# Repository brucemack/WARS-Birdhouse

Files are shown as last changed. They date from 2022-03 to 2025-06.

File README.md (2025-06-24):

WARS LoRa Birdhouse Project
===========================

Looking for a different way to tweet?  This project explores the potential of using low-cost/low-bandwidth LoRa radios to build simple mesh networks that can pass text messages around town.  Networks of this type could be useful for emergency communications or 
other applications that can take advantage of the fully-autonomous (carbon-neutral) nature of the birdhouse repeater stations. This 
project is being undertaken by members of the Wellesley Amateur Radio Society, W1TKZ.  The design is 
made available for amateur (non-commercial) purposes in the spirit of experimentation and knowledge sharing
amongst the ham community.  At the very least, we're creating homes for some lucky birds in our area.

Please contact Bruce MacKinnon (KC1FSZ) if you have technical questions.  I am 
interested in home-brew radio projects, many of which can be 
found [on my QRZ page](https://www.qrz.com/db/kc1fsz). 

The [project WIKI is located here](https://github.com/brucemack/WARS-Birdhouse/wiki).

Will this bird fly?  Let's find out!  

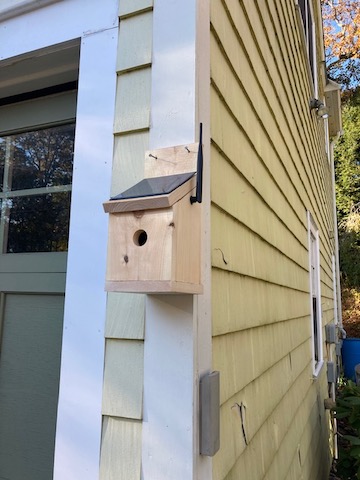
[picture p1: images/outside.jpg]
Birdhouse


Publicity
=========

* This project is mentioned in an excellent new book called [Other Networks: A Radical Technology Sourcebook](https://www.amazon.com/Other-Networks-Radical-Technology-Sourcebook/dp/1944860657) written by Dr. Lori Emerson, Associate Professor of Media Studies, Founding Director of the Media Archaeology Lab, and Director of the Intermedia Art, Writing and Performance Program at the University of Colorado Boulder. I was flattered that Dr. Emerson considered this technology to be "radical" enough to be included in her book, but it's probably not as radical as some of the other technologies she describes including a faster-than-light communications network and a pasilalinic-sympathetic compass.
* An article about this project (co-authored with Dan Brown W1DAN) appears in the Club Station column of the July 2023 issue of [ARRL QST Magazine](https://www.arrl.org/qst). It was nice of the League to publish this.
* A nice Hackaday article [can be found here](https://hackaday.com/2022/04/09/lora-powered-birdhouses-enable-wireless-networking-when-the-internets-down/).  I found this article amusing given its implication that our network could be used as a backup when the Internet was down.  I've not tried streaming Netflix over LoRa, but I'm guessing the video quality won't be great. :-)
* The Zero Retries newsletter covered the project [in June of 2023](https://www.zeroretries.org/i/126932222/thoughts-on-amateur-radio-adjacent-technologies-lora). Steve Stroh N8GNJ does a nice job with this widely-read newsletter and I was honored to be called "woefully misinformed" and "shortsighted" in his article.  As Lindsay Lohan once said, there is no such thing as bad publicity!

Design Overview
================

Nodes on the network are autonomous, solar-powered birdhouses that each contain a +20dBm/100mW radio (Semtech SX1276).  These birdhouses will run 24x7 assuming reasonable weather conditions.  USB-connected desktop nodes are used to access the network from a computer via serial connection.  An internet gateway node is also 
under development. 

LoRa range experiments have been widely documented.  Your milage will vary considerably depending on terrain, 
station hight, etc. Testing shows that 1 km link ranges are reasonable in suburban areas. 

Birdhouse packaging was chosen in order to blend into the surroundings more easily.  We want this project to be environmentally friendly.

Low-power, solar design allows the birdhouses to be 100% autonomous.  This makes it relatively easy to install a repeater station in any location that has good sun exposure and good visibility to other stations. 

The desktop station model is powered by the USB connection, does not have the battery/solar components, but 
is identical to the birdhouse repeaters from an RF/firmware perspective.

The birdhouse is run by an ESP32 microcontroller at the moment, although this decision is under  consideration.  A more power-efficient STM32 prototype is being worked on.

Commodity components are being used to keep birdhouse costs to a minimum.  Our goal is to keep the node cost under $50 USD. 

The software supports a simple message routing protocol that allows packets to "hop" between houses to reach their final destination.  Other control packets are used to extract engineering data and to control 
message routing.

The 33cm ham band (902-928 MHz) is used given that this is an experimental technology and **is not FCC Part 15 certified** at the moment.  All 
nodes must be installed/operated by FCC licensed amateur/ham radio operators under Part 97 rules.

A proof-of-concept network of 5 stations has been constructed in Wellesley, MA.  Messages have been successfully routed back and forth across the entire mesh, including hops between birdhouses that were separated by approximately 1 kilometer.  Antenna height is important, as always.  The houses have been subjected to bad New England weather conditions including snow, ice, extended periods of cloudy weather and sub-zero temperatures.  It is an open question as to how the system will perform when our trees have leaves on them again!

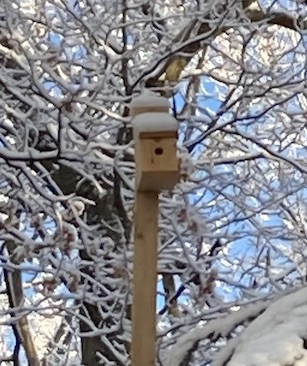
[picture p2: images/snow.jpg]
Snow


A 15 node beta network is currently in the planning stages.  This includes upgrades of the hardware and firmware.

If you are interested in _high-speed_ mesh networks built using commercial hardware this project might not be your thing.  Please take a look at AREDN (https://www.arednmesh.org) instead.  The AREDN team is doing great work.

Architecture Overview
=====================

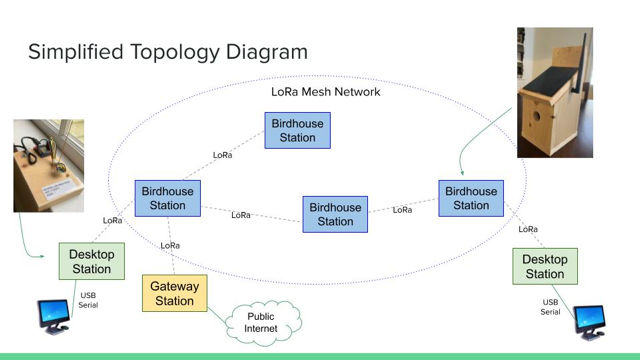
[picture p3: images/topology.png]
Architecture


How Do I Access The Network?
============================

Users access the network using desktop stations that are fitted with a USB serial port.  The desktop station runs exactly the same firmware as the birdhouse repeater.  A serial command protocol is used to send and receive messages on the network.  The desktop stations have all of the required RF components and are full-fledged nodes on the network (with their own addresses).  Desktop nodes don't use the solar/battery installation since they can be powered from the USB port.

Currently users interact with the network using a conventional serial terminal running on a PC (ie. PUTTY or something similar).  No special software is required.  A Python desktop user interface is planned to improve ergonomics.  The serial commands are described in a later section.

The expectation is that users will install a birdhouse station at some 
advantageous location on their property in order to join the network and
increase the network coverage area.  This
means that the required line-of-sight for the desktop station is much less 
important - it's a "short hop" onto  the network.

The other option is to connect the desktop station to a quality antenna 
using a longer feed-line and avoid the need for two stations.  Either configuration 
is fine.

The packaging for the desktop station has not yet been finalized.  At the moment 
the parts are mounted on a block of wood, as pictured below.  A resonant vertical antenna
and USB cable are included with the package.

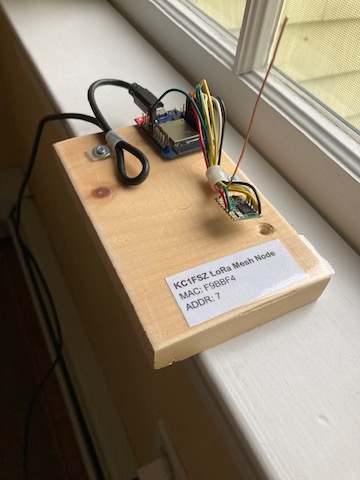
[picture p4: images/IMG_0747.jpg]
Desktop Node


How Can I Get A Birdhouse?
==========================

Hardware/firmware is still being refined as part of a club project.  All firmware, KiCAD files, and woodworking
dimensions are available on this site for anyone who wants to build a birdhouse for themselves.

After our next hardware iteration (V2) is tested we will be making the components available in kit form.

If you live in a strategic location at high elevation and you would like a fully-assembled, tested station we will be happy to provide one free of charge. :-)

Please contact the network administrator to be assigned a node address on the network.

Do I Need To Be A Ham To Use The Network?
=========================================

Yes. The radio module we are using is not Part 15 certified 
so it must be run using Part 97 (amateur) rules.  We are currently doing research on a non-ham ISM Part 15 version of the network 
to make it easy for non-licensed users to join the fun.  If anyone has expertise in this area please add a comment to [the discussion this topic in GitHub](https://github.com/brucemack/WARS-Birdhouse/discussions/2).

Per FCC rules, Part 15 and Part 97 networks will not talk to each other.

Protocol Documentation
======================

The network runs on the 33cm (902-928 MHz) amateur band.  We are running on 906.5 MHz, which lies
in the digital portion of the ARRL band plan for 33cm.  According to the New England Spectrum Management Council (NESMC, https://www.nesmc.org/) 902 MHz band plan, this frequency is in the "mixed use" section of the band.  Our frequency has been registered in the NESMC database to ensure proper coordination with other uses of this band.

The LoRa message payload is documented here in compliance with FCC regulations.  There is no encryption 
used anywhere in the design.  The information contained here is all that a listener would need to interpret the messages.

The standard LoRa physical packet format is used.  Particulars on LoRa parameters:

* 125k bandwidth mode
* CRC enabled, 4/5 coding rate
* Explicit header mode is used
* LoRa spreading factor 9
* 12 symbol preamble

Here is a summary of the physical layer packet format from the Semtech documentation:

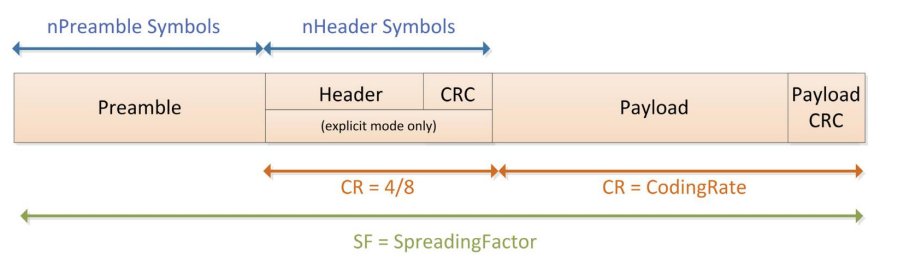
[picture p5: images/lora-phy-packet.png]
packet


A much more detailed explanation of [the LoRa encoding can be found here](https://www.epfl.ch/labs/tcl/wp-content/uploads/2020/02/Reverse_Eng_Report.pdf).

The payload above contains a 36-byte header followed by a variable length packet format.  Particulars:

* 36-byte fixed size. 
* Version (PV) is 2 (at the moment).
* Packet type (PT) describes the nature/handling of the message.  More on types below.
* Packet ID (PID) is used for acknowledgement and duplicate packet elimination.  16-bit integer (little endian).
* Call signs are in ASCII format, padded with spaces as needed.
* Source/destination addresses are 16-bit integer (little endian).  More on addresses below.

packet

### Station Addressing Scheme

Each station is assigned a 16-bit address. Some addresses have special significance:
* 0x0000: Not used
* 0x0001 through 0xffef: Used for normal stations on the network.
* 0xfff0 through 0xfffd: Un-routed stations used for administrative/maintenance purposes.
* 0xfffe: Gateway station to other meshes
* 0xffff: The broadcast address

### Packet Types

Packet types are interpreted as follows:
* 0: Not used
* 1: General acknowledgement packet, used for reliable delivery.
* 2: Station ID/beacon packet.
* 3: Ping request.
* 4: Ping response (pong).
* 5: Station engineering data request.
* 6: Station engineering data response.  
  * See below for details of response.
* 7: Network path test request.  
  * Stations will add their node ID and last-hop RSSI data to this message as it is routed through the network.
* 8: Network path test response.  
  * Stations will add their node ID and last-hop RSSI data to this message as it is routed through the network.
* 9: Set security seed.  Used to establish the seed used to validate privileged requests.
* 10: Set route request.  (A privileged operation)
* 11: Get route data request.
* 12: Get route data response.
* 13: Discover route request (FUTURE USE).
* 14: Discover route response (FUTURE USE).
* 15: Station reset request. (A privileged operation)
* 16: Set station clock request. (A privileged operation)
* 17: Reset engineering counters request.
* 18: Firmware update request (FUTURE USE, privileged)
* 19-31: (RESERVED)
* 32: Routine text traffic.
  * ASCII, free-text payload.  Variable size, max size is 128 bytes.
* 33: Priority/emergency text traffic.
  * ASCII, free-text payload.  Variable size, max size is 128 bytes.
* 34: Routine binary/data traffic.
  * Variable size, max size is 128 bytes.  *NO ENCRYPTION ALLOWED!*
* 35: Priority/emergency binary/data traffic.
  * Variable size, max size is 128 bytes.  *NO ENCRYPTION ALLOWED!*
* 36: Station alert.  Used for sounding audible alarms, etc.

### Acknowledgement/De-Duplication 

Most packet types are acknowledged on each hop.  Packet type 1 is used for this purpose.  Note that this 
doesn't mean that the acknowledgement reaches the original sender, it just means that each 
station will get an ACK to indicate that a packet has been handed off to the next station in 
the route path.

Acknowledgement packets (type 1) and Station ID packets (type 2) are not acknowledged.

Stations will maintain a counter for each node that is receives packet from.  Duplicate packets
will be discarded based on the Packet ID counter.  A window will be used to avoid confusion when 
the counter wraps.

#### Station Engineering Data Packet

This packet returns technical data that is used to monitor the state of 
a station.  Format is a follows:

* 0-1: Firmware version 
* 2-3: Battery voltage in mV
* 4-5: Panel voltage in mV
* 6-9: Uptime in seconds
* 10-13: Time (in seconds since the epoch)
* 14-15: Boot count
* 16-17: Sleep count 
* 18-19: Receive packet count 
* 20-21: Routing error count
* 22-23: Temperature (when option installed)
* 24-25: Humidity (when option installed)
* 26-27: Device class
  * 0: Unspecified
  * 1: WARS Desktop ESP32
  * 2: WARS Birdhouse ESP32
  * 3: WARS Mesh gateway STM32
  * 4: WARS Internet gateway STM32
  * 5: WARS Desktop STM32
  * 6: WARS Birdhouse STM32
* 28-29: Device revision
* 30-31: Wrong-node receive packet count 

2 byte and 4 byte integers are in little-endian format.

Hardware Overview (Electronics)
===============================

The birdhouse repeater prototype (external view):

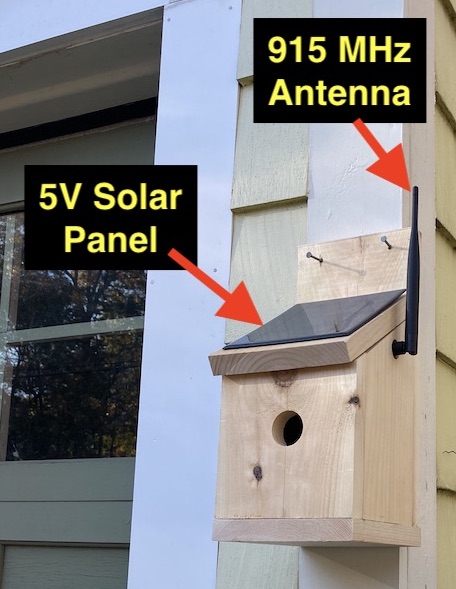
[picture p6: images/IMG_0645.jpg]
house1


The birdhouse repeater prototype (internal electronics view):

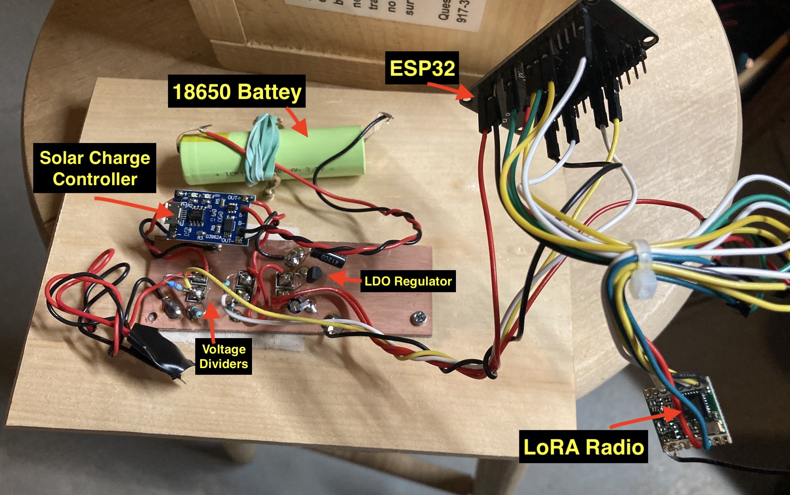
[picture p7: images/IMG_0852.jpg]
house2


A tower-mounted birdhouse repeater prototype at the QTH of KC1FSZ:

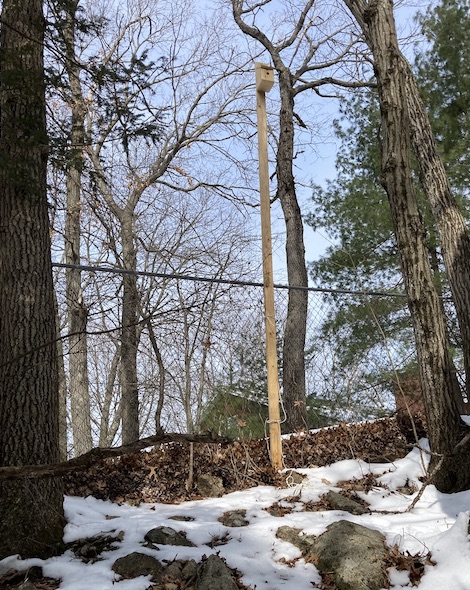
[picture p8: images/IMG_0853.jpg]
house3


A custom PCB (V2) has been developed to improve integration and to make things easier for kit builders without SMD soldering capability.  This board also provides an SMA connector to make antenna experimentation easier.

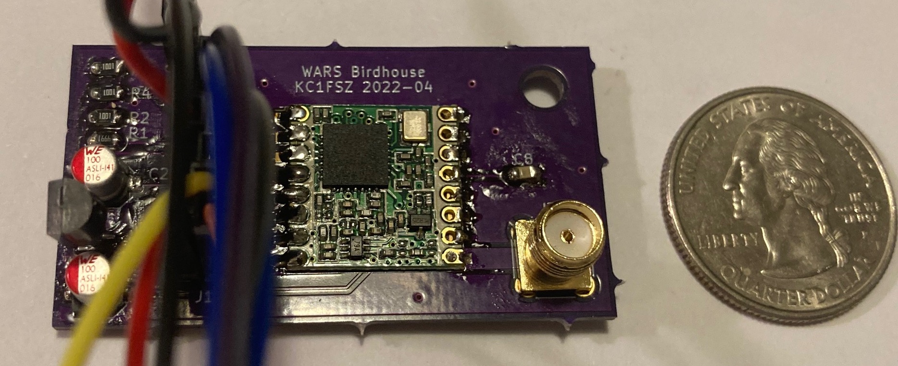
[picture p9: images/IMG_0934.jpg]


Hardware Notes
--------------
* Voltage readings are taken on solar panels and batteries.
* The V2 schematic can be found [here](https://github.com/brucemack/WARS-Birdhouse/blob/main/kicad/WARS%20Birdhouse%20V2.pdf).

Hardware Overview (Woodwork)
============================

Repeater nodes are packaged in a standardized birdhouse enclosure that was designed for easy assembly.  
Six pieces of wood are required.  Components are attached using wood screws.  The birdhouse is fully
functional for small bird species.    

The roof is sloped at a 32 degree angle according to the recommended optimal configuration for 
solar generation at 42 degrees North latitude where the initial network was deployed. The design
may need to be adjusted for other locations.  

The wood parts for the birdhouse repeater prototype:

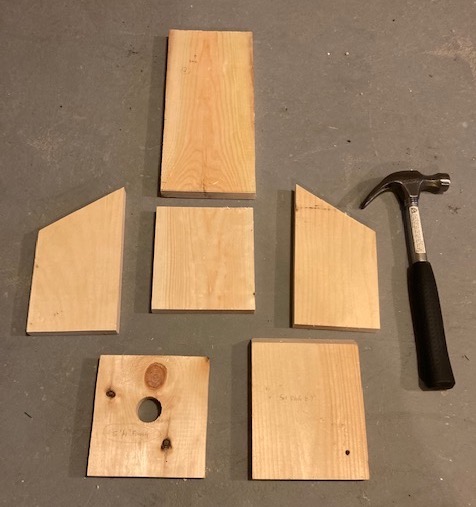
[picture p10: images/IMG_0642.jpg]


A tree-mounted repeater prototype installed in a tree inside of a cloverleaf on-/off-ramp:

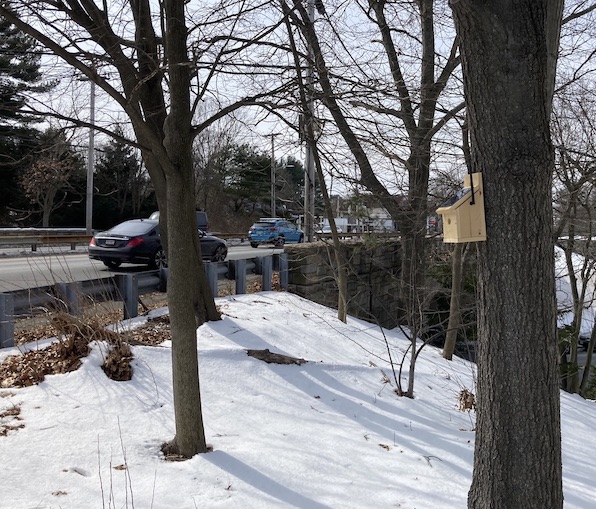
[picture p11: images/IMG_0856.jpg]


A repeater station mounted on the top of North Hill in Needham, MA.

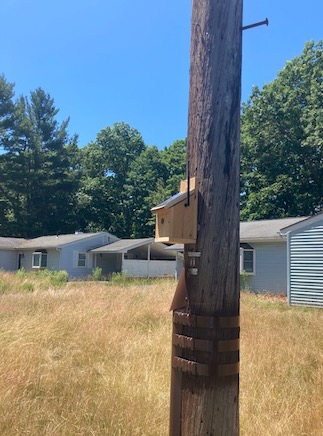
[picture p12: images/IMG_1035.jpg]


Lumber Cut List:

* 1"x5" nominal stock (4.5" actual)
  * Sides: 6 1/2" max length with 32 degree mitre
* 1"x6" nominal stock (5.5" actual)
  * Back: 10" length
  * Bottom: 6" length
  * Roof: 7 1/4" length with 32 degree bevel on table saw.  (Set fence at 6 1/2")
  * Front: 3 3/4" max length with 32 degree bevel on table saw. Hole 1 1/2" diameter.  (Measure this peice using side and adjust fence accordindly).

**PLEASE USE CAUTION WHEN WORKING WITH POWER TOOLS!**

Software Overview
=================

The LoRa software is completely homebrew - no off-the-shelf drivers are being used.  This
means much more work, and much more learning.

All nodes support a serial interface for interacting with the network, but this is only connected for desktop nodes.  

The serial command processor is implemented using this [very good project](https://github.com/philj404/SimpleSerialShell) by Phil Jensen.

A static routing mechanism is being used at the moment.  The routing table for each node can be changed remotely.  Dynamic routing will be developed in a future phase.

Developer Information
=====================

Please see the [project WIKI](https://github.com/brucemack/WARS-Birdhouse/wiki) for information on development, IDE setup, etc.

Related Technology
==================

* AREDN (Amateur Radio Emergency Mesh Network): A very cool
system that leverages WIFI technology to create off-grid
IP networks that support emergency communications.  These guys are doing much higher speeds and 
are using much more sophisticated hardware.  The WARS Birdhouse project uses a different 
wireless technology and is not interoperable with the ARDEN system.  See https://www.arednmesh.org. 
* LoRaHAM (https://github.com/travisgoodspeed/loraham): A great open-source project that explored some similar territory.  The project appears to be inactive at this time.
* LoRaWAN: A cool system that uses LoRa stations organized in a star topology.  The hub of each star is a gateway to the public internet.  This technology uses encryption and is not legal for amateur projects. 
* DASH7 wireless network (https://en.wikipedia.org/wiki/DASH7).  Uses encryption, so not good for Part 97, but interesting nonetheless.  

Reference Material
==================

* Radio Mobile by VE2DBE: https://www.ve2dbe.com/english1.html is a great program for understanding local-area/LOS propagation. 
* The Ubiquity Link Planner is very helpful for understanding land features between 
potential station sites: https://link.ui.com/#.2q
* LoRa rules, regulations, and terminology: https://lora.readthedocs.io/en/latest/#rules-and-regulations
* Reference for LoRa radio module (RFM95W): https://www.hoperf.com/modules/lora/RFM95.html
* LoRa Modulation Information: https://www.frugalprototype.com/wp-content/uploads/2016/08/an1200.22.pdf
* Reference for 18650 battery: https://cdn.sparkfun.com/datasheets/Prototyping/ICR18650%202600mAH%20datasheet.pdf
* Reference for LDO Voltage Regulator: https://ww1.microchip.com/downloads/en/DeviceDoc/MCP1700-Low-Quiescent-Current-LDO-20001826E.pdf
* Reference for STM32L031 microcontroller: https://www.st.com/resource/en/datasheet/stm32l031k6.pdf
* STM32L0 hardware design guide: https://www.st.com/resource/en/application_note/an4467-getting-started-with-stm32l0xx-hardware-development-stmicroelectronics.pdf
* Reference for the ESP32 D1 Mini: https://wiki.csgalileo.org/_media/projects/internetofthings/d1_mini_esp32_-_pinout.pdf
* An article on correcting non-linearity in the ESP32 AD converter: https://github.com/e-tinkers/esp32-adc-calibrate
* Datasheet for the W5500 which is used to create the bridge to an IP network: https://cdn.sparkfun.com/datasheets/Dev/Arduino/Shields/W5500_datasheet_v1.0.2_1.pdf
* A very interesting paper talking about the reverse-engineering of the LoRa physical layer: https://www.epfl.ch/labs/tcl/wp-content/uploads/2020/02/Reverse_Eng_Report.pdf

Detailed Parts List
-------------------
(To follow)

Hookup Notes
------------

Column 1

Row 0 - GND
Row 1 - Supply GND
Row 2 - IO33 (Battery Voltage Sense)
Row 3 - IO34 (Panel Voltage Sense)
Row 4 - Supply +VCC
Row 5 - Pannel
Row 6 - Pannel
Row 7 - +3.3V

Column 2

Row 0 
Row 1
Row 2 - IO19 (SPI MISO)
Row 3 - IO23 (SPI MOSI)
Row 4 - IO18 (SPI SCK)
Row 5 - IO5  (SPI NSS)
Row 6 - IO26 (Radio RST)
Row 7 - IO4  (Radio DIO0) 

Areas for Further Experimentation
=================================

Hardware 2.0 (In Process)
-------------------------
* Fully integrated PCB using surface mount components
* Switch to a ultra-low-power microprocessor: STM32L031
* SMA connector for more robust antenna experimentation

Hardware (Future)
-----------------
* Replace the linear regulator with a boost converter to improve battery usage.
* Complete the packaging of the birdhouse to ensure weatherproofing and full compatibility with avian residency.
* Cheaper antennas.
* Gain antennas for longer distance links.
* RF switch to allow dynamic switching between two antennas.  This might facilitate A/B testing, or possibly stations that have a directional/gain antenna for trunking and an omni-directional antenna for local access.
* A hand-held station with an LCD RSSI display for scouting potential station locations.

Software
--------
* Improved power efficiency using more aggressive sleeping.  Leverage the SX1276 receive interrupt or channel activity detection (CAD) interrupt to allow the system to sleep during periods of inactivity.
* Dynamic route discovery. At the moment the routes are static, but they can be modified over-the-air.
* Store and forward for times when a node is offline.
* Message sequence to avoid duplicate delivery.
* Network time synchronization.
* A more user-friendly desktop application written in Python.  This will make it easer for casual users of the work.
end-users to interact with the network.
* Network security.
* Over-the-air (OTA) software upgrades.

Relevant FCC Regulations/Notes
==============================

* Part 97.311 Defines spread-spectrum (SS) rules.
* Part 97.303 (N) Defines rules for the 33cm band.  Basically, hams must share the band with other services.  There are also geographical restrictions in Texas, New Mexico, Colorado, and Wyoming.
* Part 97.309 (B) Talks about unspecified data emission codes.  Basically, all formats need to be clearly documented. See above. 
* This firm does certification and [provides a detailed guide on the certification process](https://www.sunfiretesting.com/LoRa-FCC-Certification-Guide/).  

Copyright Information 
=====================

Copyright (C) 2023 - Bruce MacKinnon KC1FSZ

This work is covered under the terms of the GNU Public License (V3).  Please consult the 
LICENSE file for more information.  

This work is being made available for non-commercial use by the amateur radio community. Redistribution, commercial use or sale of any part is prohibited.

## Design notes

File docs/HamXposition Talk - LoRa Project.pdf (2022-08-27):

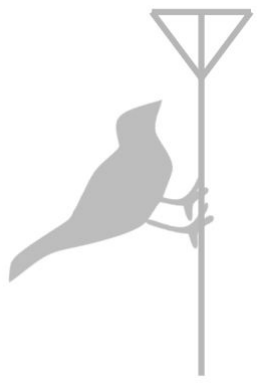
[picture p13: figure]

Wellesley Amateur Radio Society
LoRa Birdhouse Mesh Network Project

HamXposition 2022

Bruce MacKinnon KC1FSZ

## Homebrew HF Rig

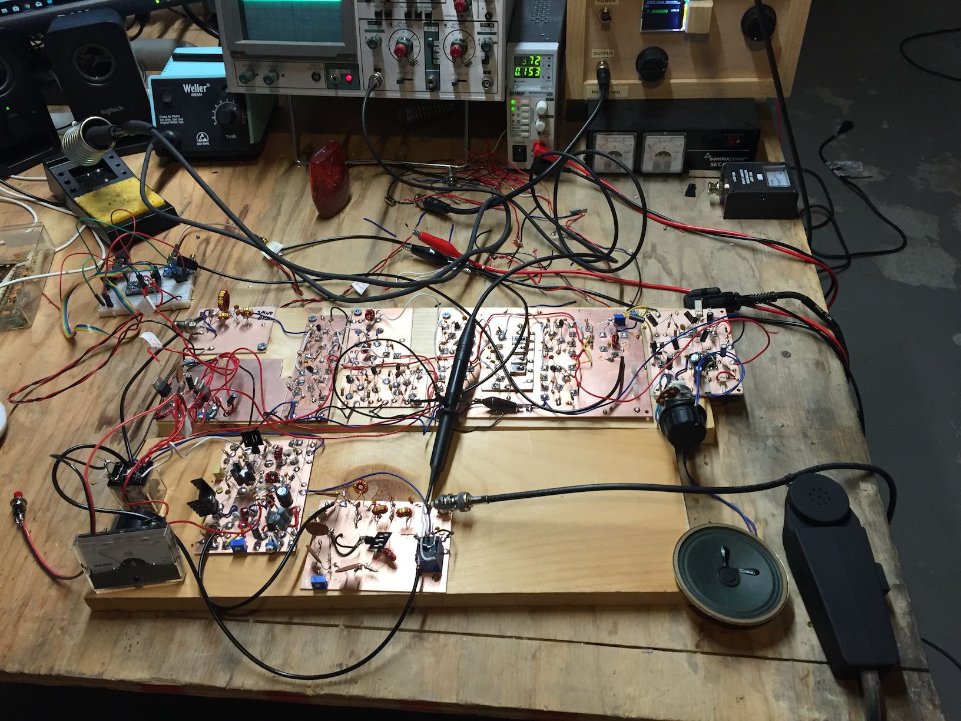
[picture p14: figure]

## Homebrew HF Rig

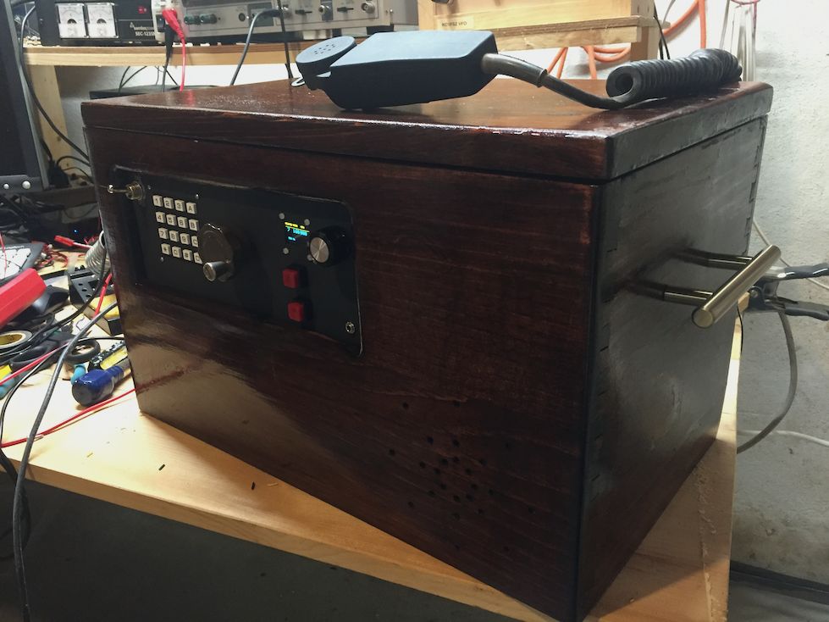
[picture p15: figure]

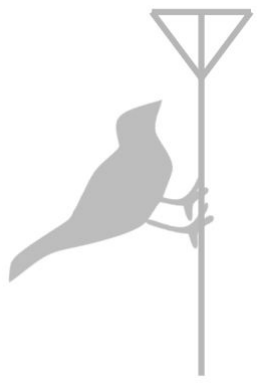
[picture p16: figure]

# Project Goals

# Project Overview

## LoRa Mesh Birdhouse Station

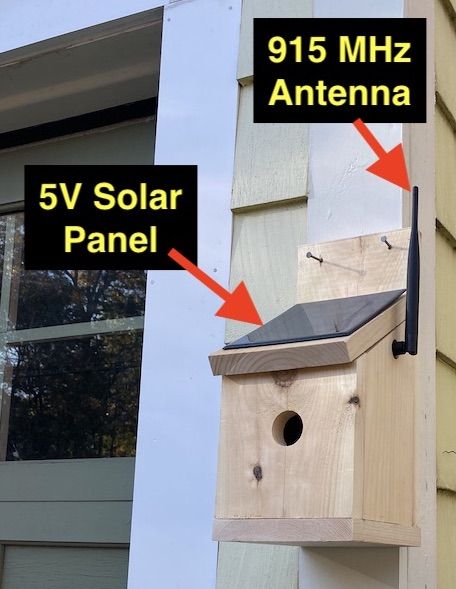
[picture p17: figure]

## LoRa Mesh Desktop Station

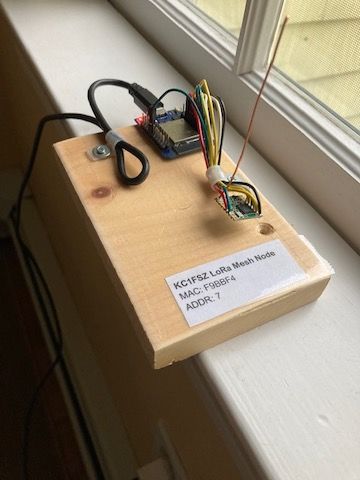
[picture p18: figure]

## Why Birdhouses?

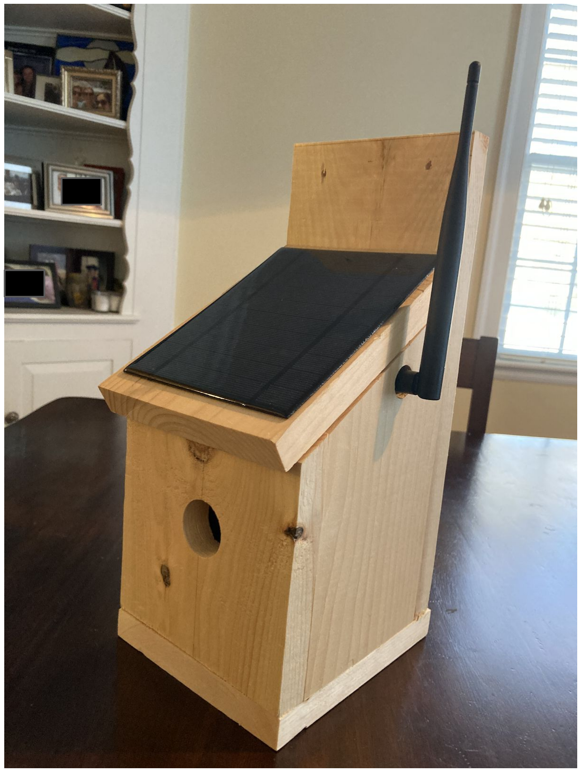
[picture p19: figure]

# Packaging Study - Focus Group

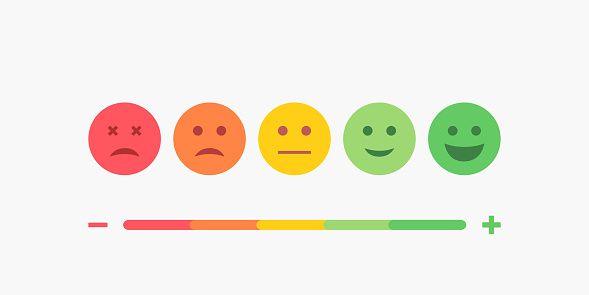
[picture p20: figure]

## Focus Group Question #1

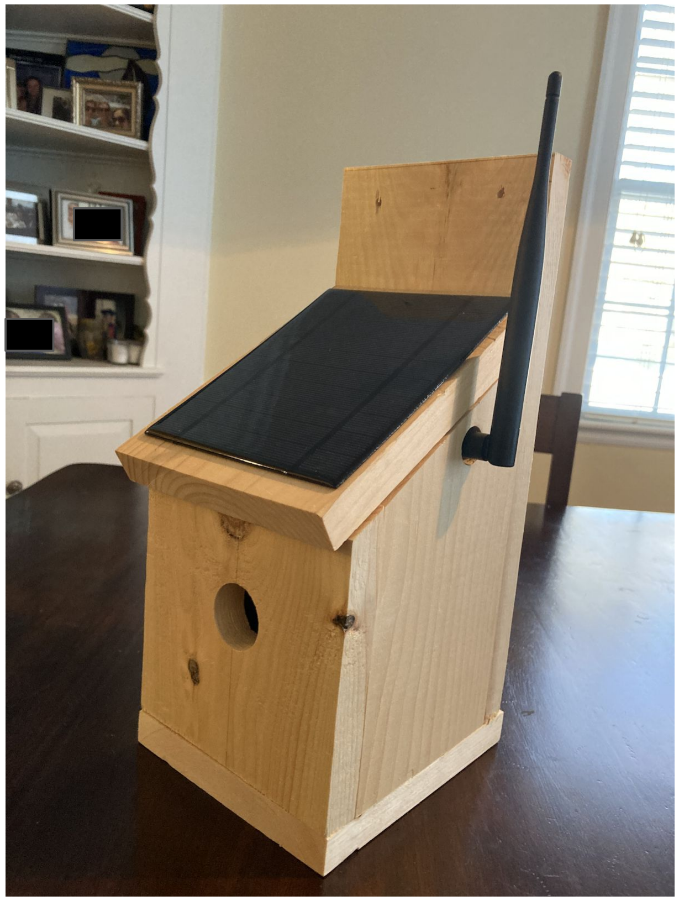
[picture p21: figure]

## Focus Group Question #1

## 1. Birds

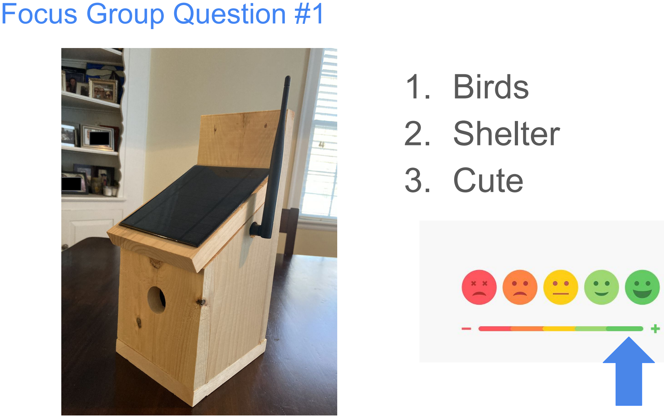
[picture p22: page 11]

## 2. Shelter 3. Cute

## Focus Group Question #2

## Focus Group Question #2

## 1. Controller

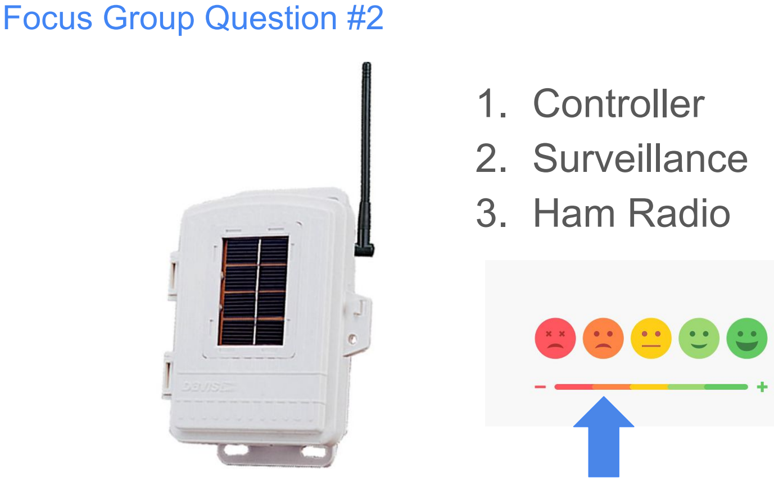
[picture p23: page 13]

## 2. Surveillance 3. Ham Radio

## Simplified Topology Diagram

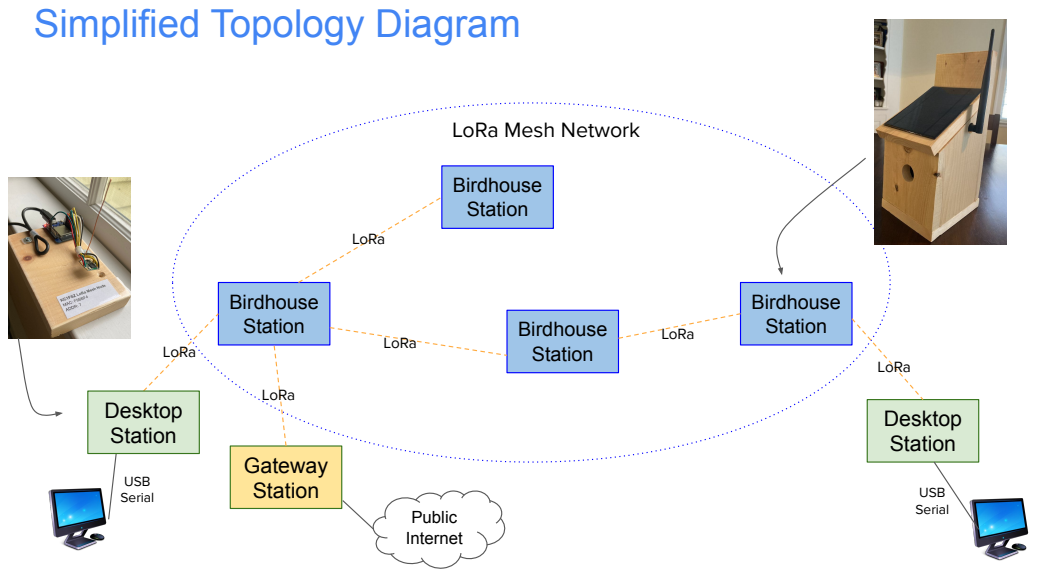
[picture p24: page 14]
Birdhouse Station; Desktop Station; Gateway Station USB; Serial; USB; LoRa; Public Internet

LoRa Mesh Network

## What Can The Network Do? (+/-s)

# Mesh Networking Basics

## Simple Topology



## Routing Table Configurations

(Configured in advance)

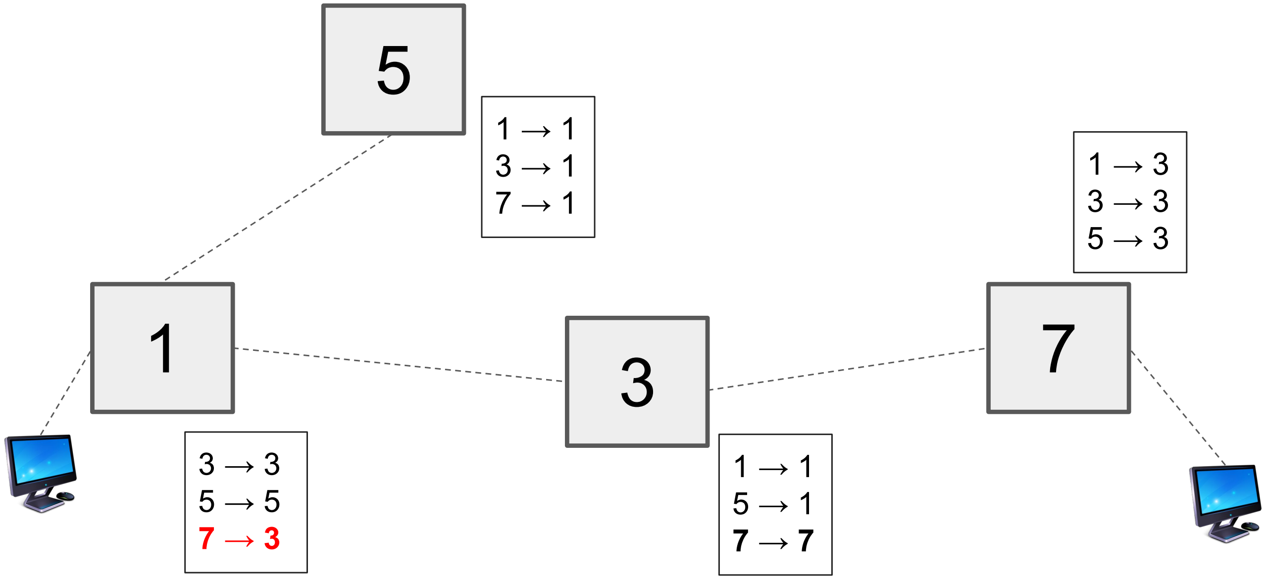
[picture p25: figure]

## Command to Send Message

t 7 “Good morning Charlie, how’s the weather over there?”

## First Hop

1
3

5

3 → 3
5 → 5
7 → 3

Station 3 is used to handle traffic for station 7. Station 5 hears, but ignores traffic.

## Second Hop

3

7

1 → 1
5 → 1
7 → 7

## Packet Format

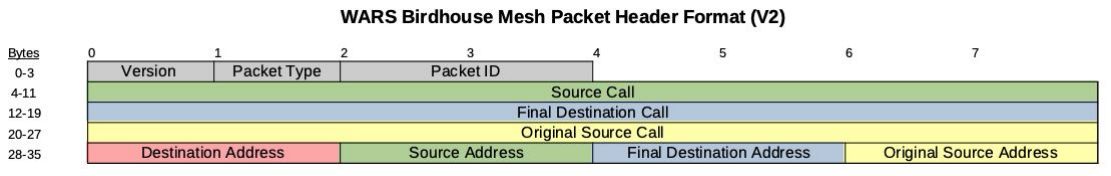
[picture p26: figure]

# Radio Stuff

## V1 Prototype Hardware

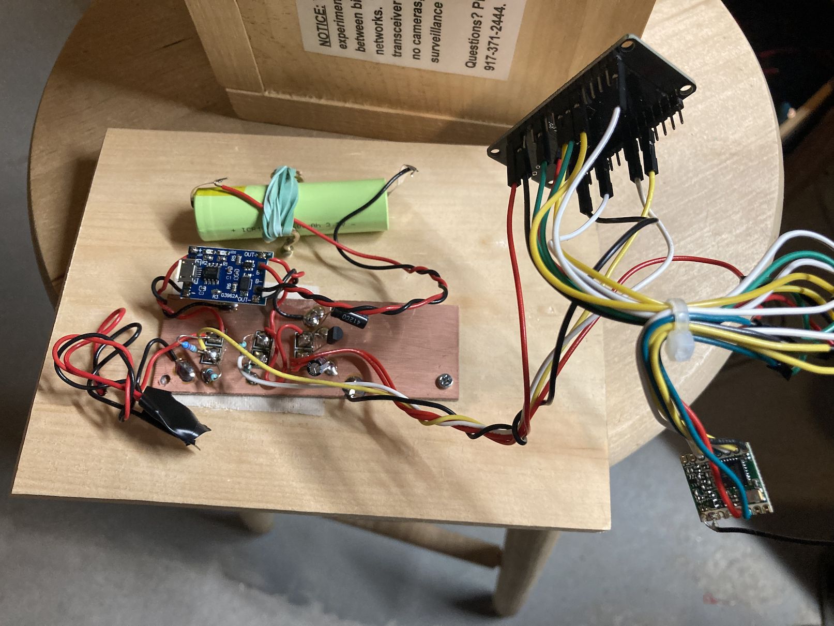
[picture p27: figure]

## V2 Integrated PCB

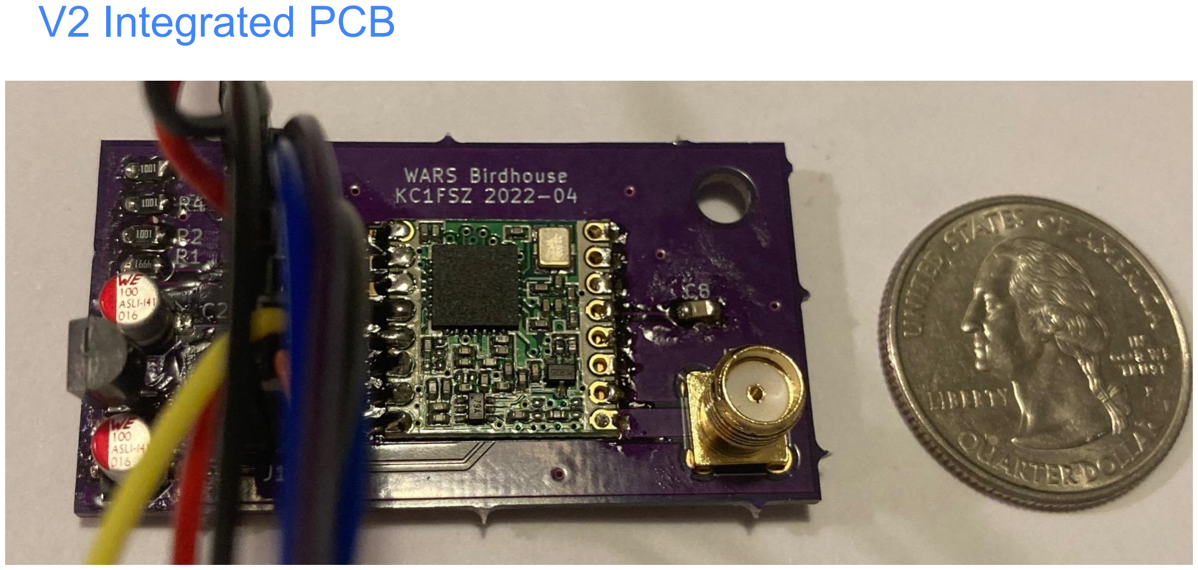
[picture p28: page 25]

# Introduction to LoRa™

## LoRa Waterfall

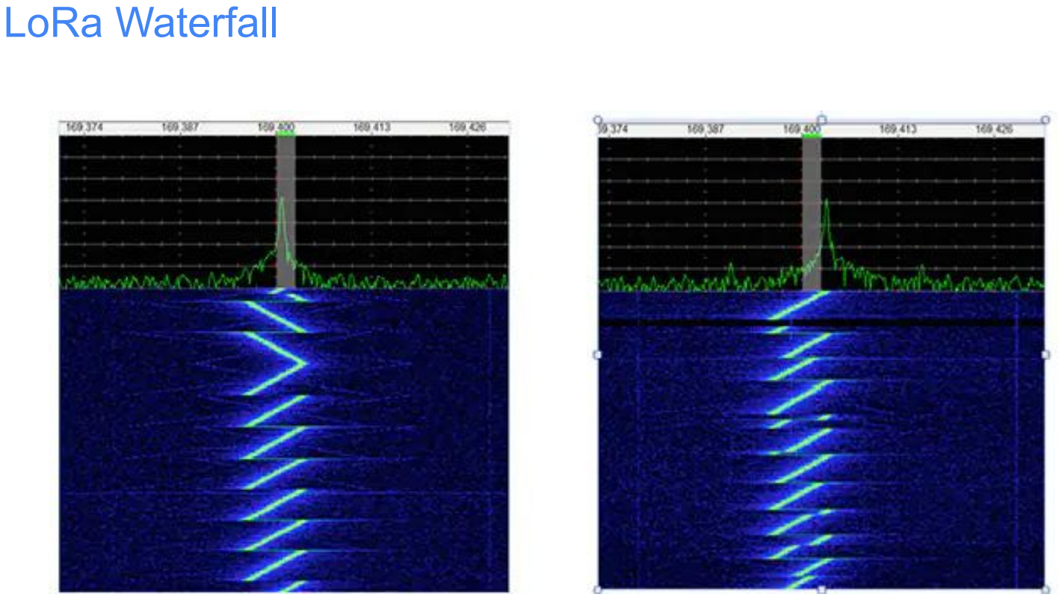
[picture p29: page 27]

## LoRa Modulation/Encoding Details

- Important Parameters
- Modulation
■ | Bandwidth (narrower = slower, more noise immunity)
■ | Spreading Factor (higher = slower, more noise immunity, more power required)
- Coding Rate (controls how much coding redundancy is in the message, data/FEC ratio)
- We are using:
- 125 KHz
- SF9
- CR 4:5
- Implies a data rate = 1,760 bits per second

## Chirp Modulation

## FSK Symbols (this is not LoRa!)

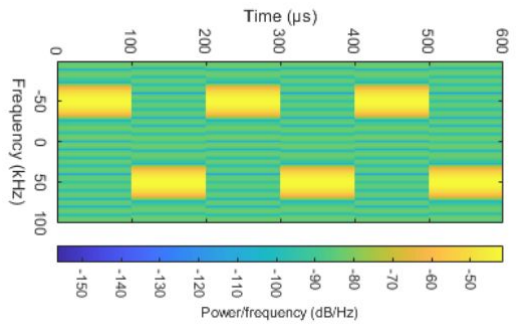
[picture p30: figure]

symbol=’0’

symbol=’1’

## LoRa Chirp Symbols

## LoRa Reverse Engineering

Matt Knight, security researcher

Presented in 2016 at DEFCON and the JailBreak Security Summit

Used GNU Radio

A good paper was also written by grad students at EPFL (École polytechnique fédérale de Lausanne) in Switzerland. Swiss Federal Institute of Technology.

## LoRa/SX1276 Physical Layer

(Very little structure, extremely versatile)

# Hardware Details

(Champagne Capabilities at Beer Prices)

## Semtech SX1276

- Semtech’s first LoRa product
- QFN28 package (SMD)
- +20 dBm (100mW) power amplifier
- 3.3V part
- ~10 mA receive
- ~140 mA transmit
- SPI interface (Serial Peripheral Interface)
- More than 100 internal reigsters

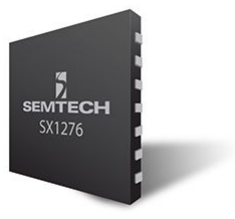
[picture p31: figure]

- $7 in 100 units on DigiKey (Thank you municipal water systems!)

## HopeRF RFM95W Module

- Chinese (Shenzhen) IoT manufacturer
- Integrates Semtech SX1276 with crystal oscillator and power conditioning

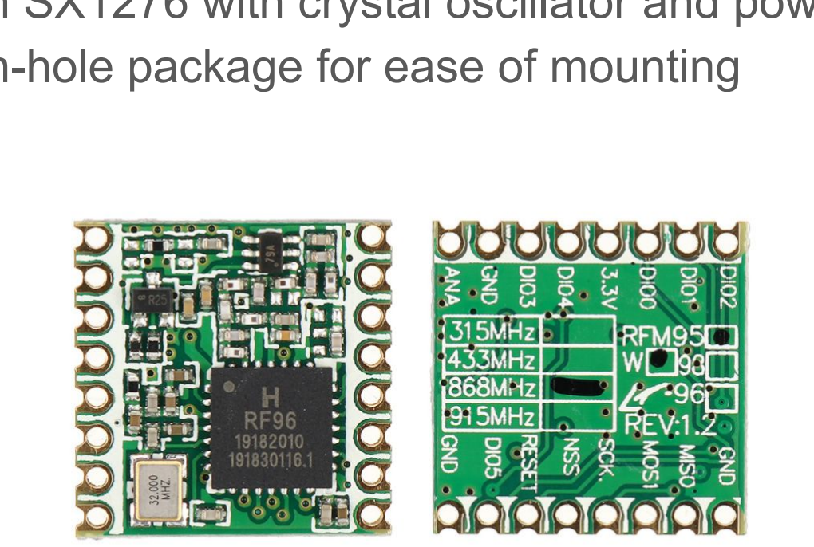
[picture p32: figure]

- Castellated/through-hole package for ease of mounting
- 3.3V supply
- Approximately $10

## Commodity Antennas

- Turns out that cheap 900 MHz antennas are widely available (Thank You LoRaWAN and Helium Network!!)
- Most likely colinears: +3dBi

## ESP32

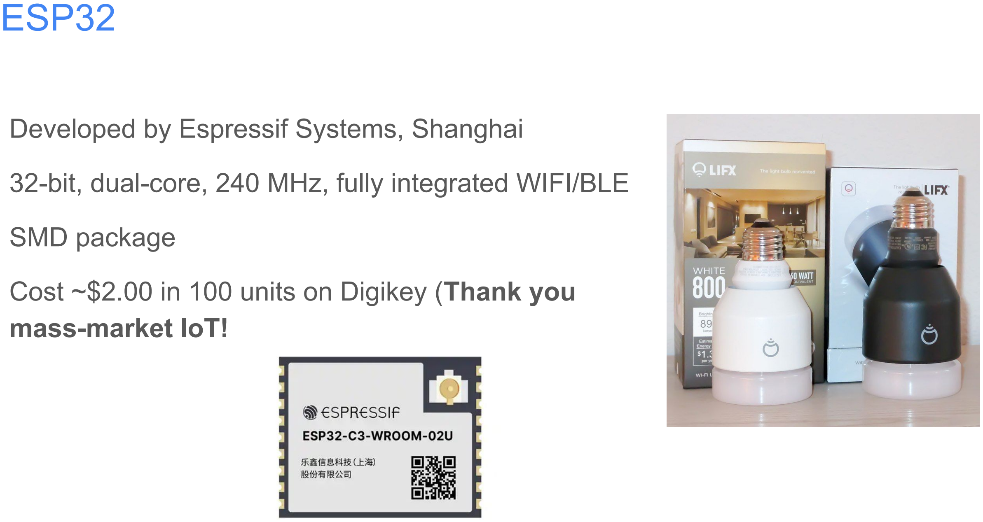
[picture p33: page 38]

Developed by Espressif Systems, Shanghai

32-bit, dual-core, 240 MHz, fully integrated WIFI/BLE

SMD package

Cost ~$2.00 in 100 units on Digikey (Thank you mass-market IoT!

## ESP32-WROOM Module

ESP32 + flash memory + support components + WIFI/BLE antennas

Fully integrated module (SOIC)

Castellated pads (SMD)

About .5 MB RAM, 1 MB of Flash ROM

+3.3V supply

Cost: ~$3.50 (Thank you IoT market!)

## ESP32 D1 Mini Module

WROOM module + voltage regulator + USB interface + LEDs

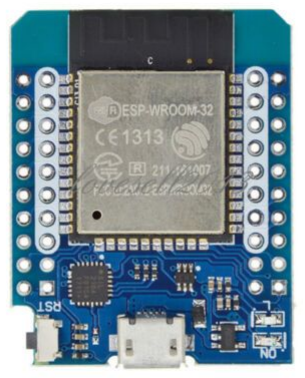
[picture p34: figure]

Convenient through-hole package

Cost: ~$7.00 (Thank you maker mass-market!)

One of many similar development modules

Power is a problem

- Full default: ~240mA
- WIFI/BLE disabled: ~120mA
- Clock reduced, LEDs removed, LDO reg: ~40mA
- Deep sleep: ~8mA

## Solar Panel and Charge Controller

2.5W, 4V solar panel, $6.50 each

TP4056 Li-Ion charge controller, $0.75 (Thank you cheap walkway lights @HD!)

## Battery

18650 Li-Ion battery

~3.7V, ~2,600 mAh

Widely used, commoditized, ~$6.00 (Thank you E-Cigarettes Smokers!!)

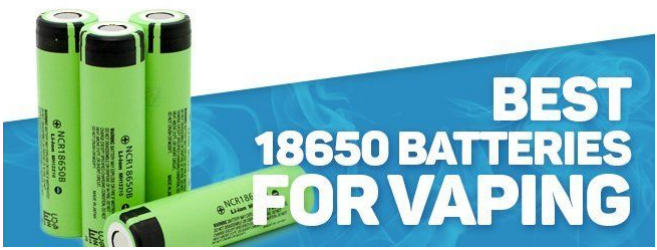
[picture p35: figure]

## Forest Products

Douglas Fir

Inexpensive, biodegradable, and fully renewable, through good forest management.

(Thank you Mother Nature!)

# Power Management

## Snow Birds

# Software Notes

# Future Directions

## 14’ Tower - Height Matters!

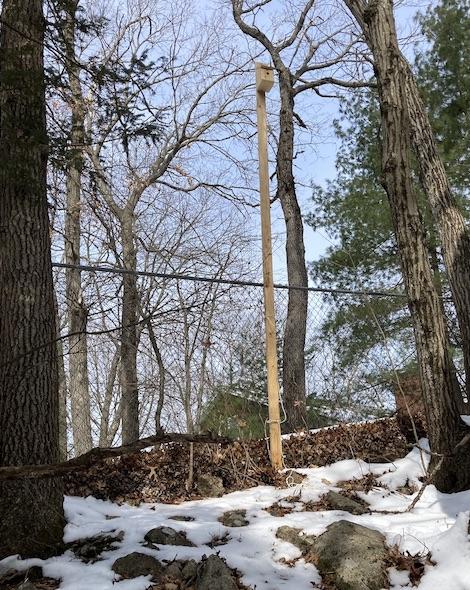
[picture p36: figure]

## Thank You For Your Interest!

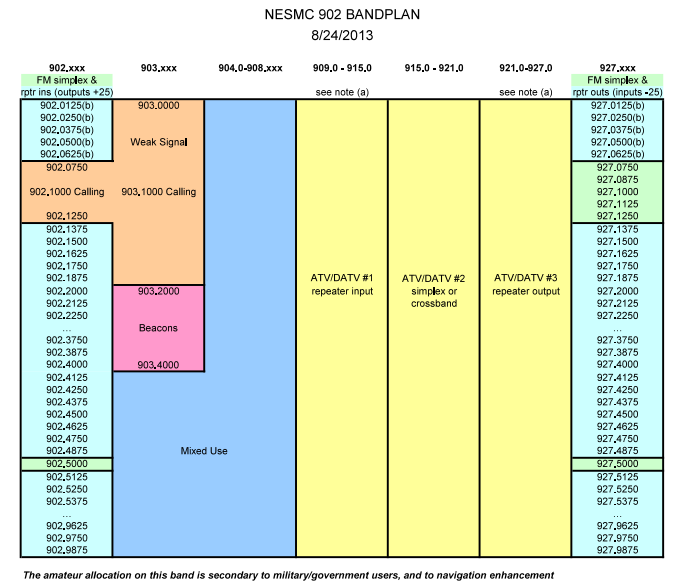
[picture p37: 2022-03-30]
images/bandplan.png

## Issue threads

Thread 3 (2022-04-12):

README doesn't address lithium ion battery charging and temperature

gdt, 2022-04-12:
I am not entirely clear on the details, but my impression is that lithium ion batteries must not be charged below 0C or they will be destroyed.  I have seen batteries with heater boxes, and mostly people use these batteries indoors.    Obviously around EMA temps are well below 0C some of the time.   It would be nice to add an explanation of this issue.

I am curious if these operated through the winter and what the experience was with sub-0C charging.

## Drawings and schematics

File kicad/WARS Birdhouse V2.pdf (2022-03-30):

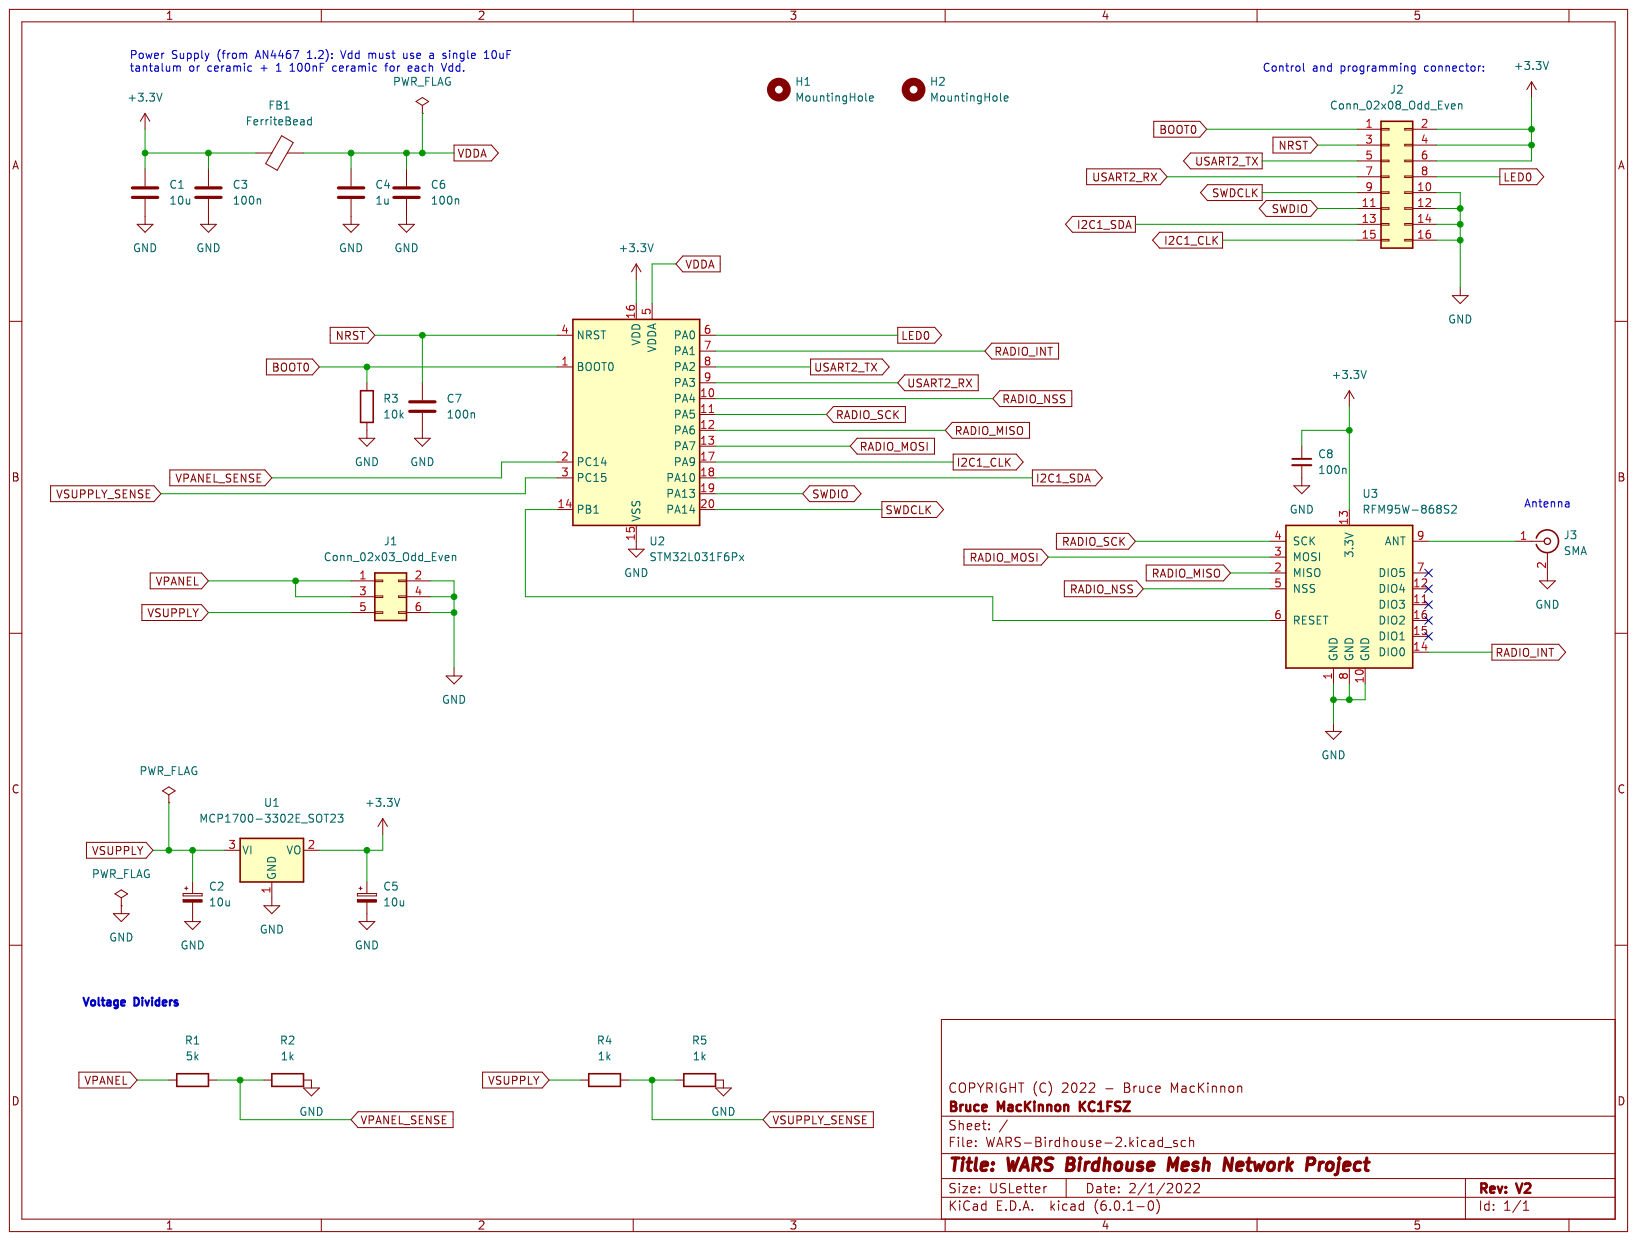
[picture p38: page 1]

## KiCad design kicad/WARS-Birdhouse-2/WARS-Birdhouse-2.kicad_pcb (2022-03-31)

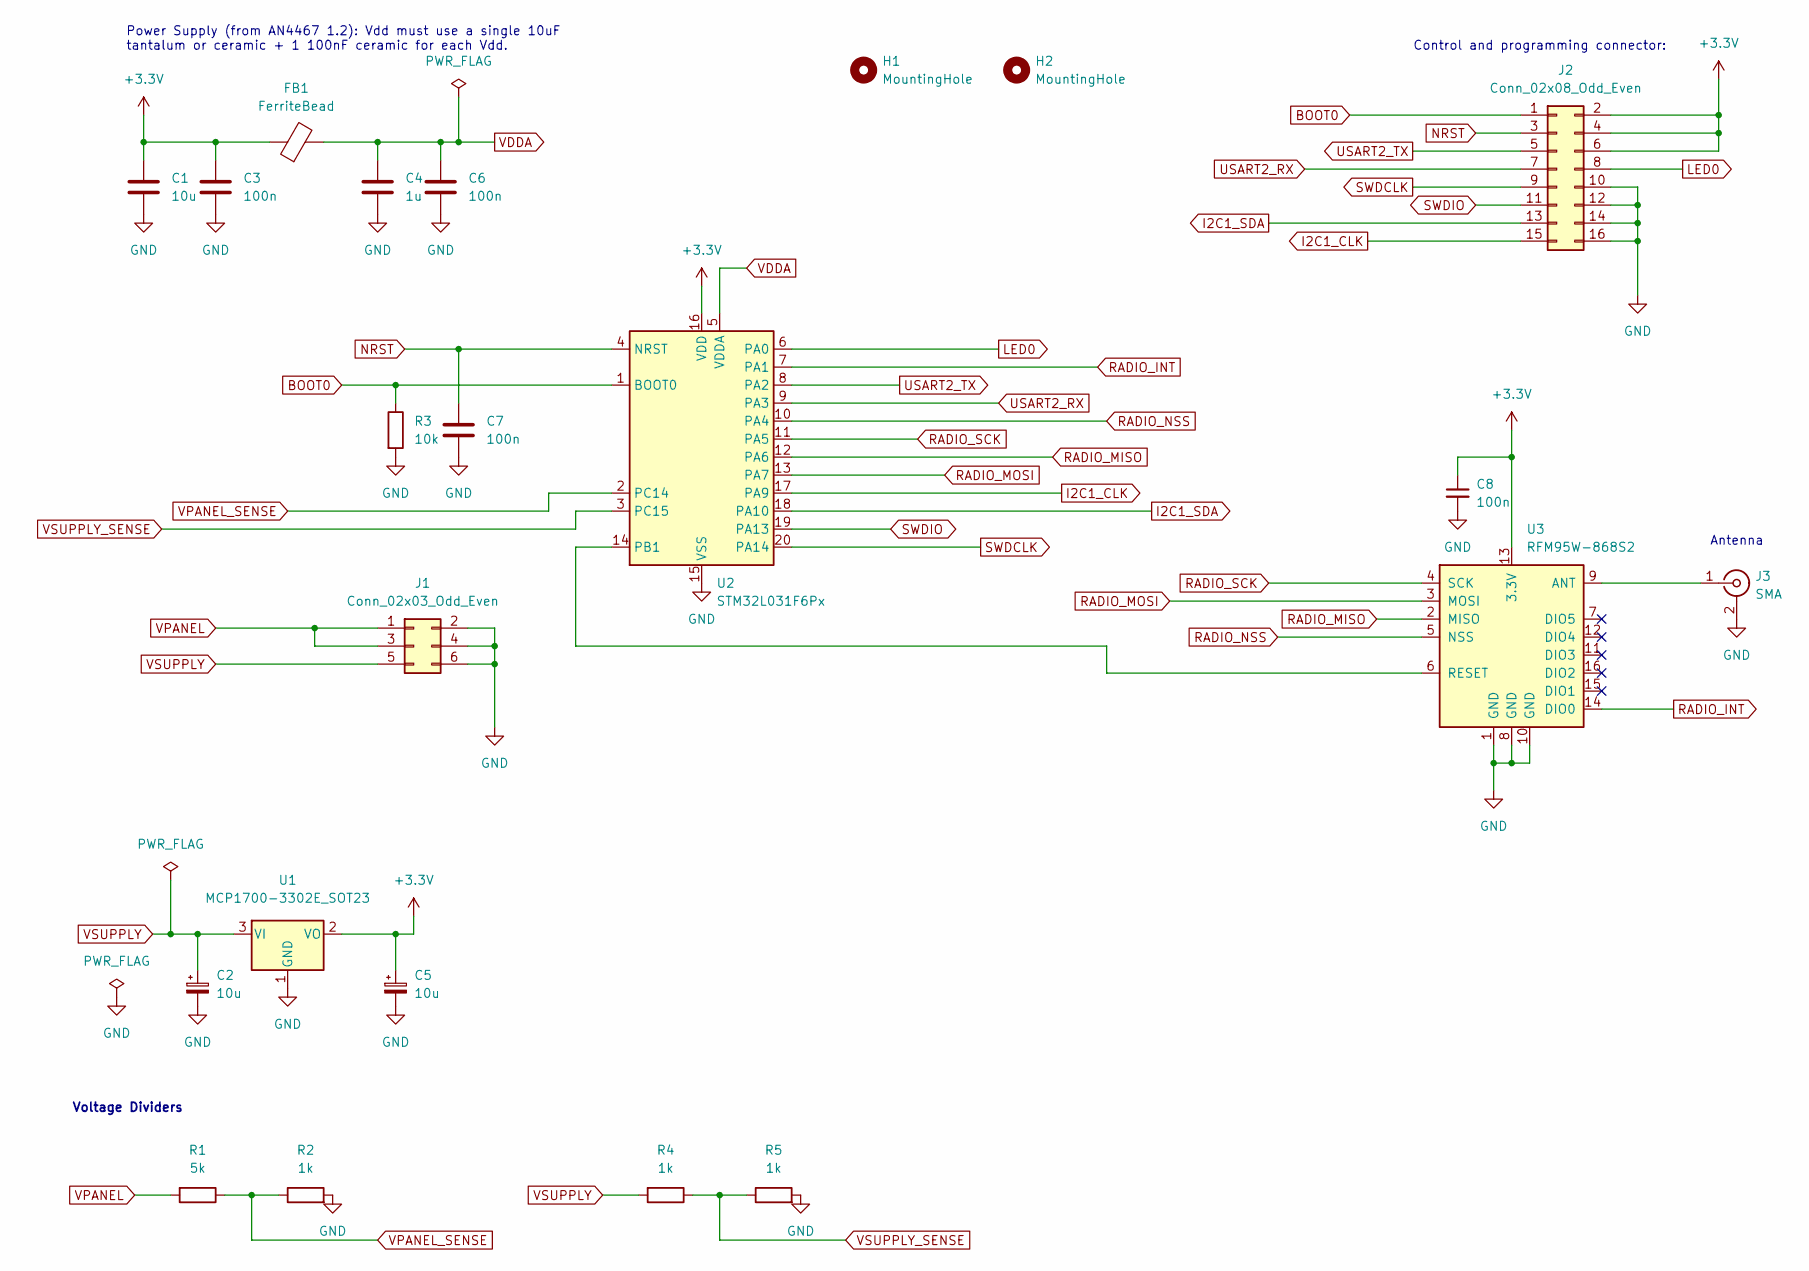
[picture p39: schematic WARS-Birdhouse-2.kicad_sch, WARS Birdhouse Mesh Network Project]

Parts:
C1: 10u; CP_EIA-3216-10_Kemet-I_Pad1.58x1.35mm_HandSolder
C2, C5: 10u; CP_Elec_4x5.4
C3, C6, C7, C8: 100n; C_0805_2012Metric_Pad1.18x1.45mm_HandSolder
C4: 1u; C_0805_2012Metric_Pad1.18x1.45mm_HandSolder
FB1: FerriteBead; C_0805_2012Metric_Pad1.18x1.45mm_HandSolder
H1, H2: MountingHole; MountingHole_4mm
J1: Conn_02x03_Odd_Even; PinHeader_2x03_P2.54mm_Vertical
J2: Conn_02x08_Odd_Even; PinHeader_2x08_P2.54mm_Vertical
J3: SMA; SMA_Amphenol_132134_Vertical
R1: 5k; R_0805_2012Metric_Pad1.20x1.40mm_HandSolder
R2, R4, R5: 1k; R_0805_2012Metric_Pad1.20x1.40mm_HandSolder
R3: 10k; R_0805_2012Metric_Pad1.20x1.40mm_HandSolder
U1: MCP1700-3302E_SOT23; SOT-23
U2: STM32L031F6Px; TSSOP-20_4.4x6.5mm_P0.65mm
U3: RFM95W-868S2; HOPERF_RFM9XW_SMD

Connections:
+3V3: C1.1, C3.1, C5.1, C8.1, FB1.1, J2.2, J2.4, J2.6, U1.2 (VO), U2.16 (VDD), U3.13 (3.3V)
BOOT0: J2.1, R3.1, U2.1 (BOOT0)
GND: C1.2, C2.2, C3.2, C4.2, C5.2, C6.2, C7.2, C8.2, J1.2, J1.4, J1.6, J2.10, J2.12, J2.14, J2.16, J3.2 (Ext), R2.2, R3.2, R5.2, U1.1 (GND), U2.15 (VSS), U3.1 (GND), U3.8 (GND), U3.10 (GND)
I2C1_CLK: J2.15, U2.17 (PA9)
I2C1_SDA: J2.13, U2.18 (PA10)
LED0: J2.8, U2.6 (PA0)
NRST: C7.1, J2.3, U2.4 (NRST)
unnamed: J3.1 (In), U3.9 (ANT)
unnamed: U2.14 (PB1), U3.6 (RESET)
RADIO_INT: U2.7 (PA1), U3.14 (DIO0)
RADIO_MISO: U2.12 (PA6), U3.2 (MISO)
RADIO_MOSI: U2.13 (PA7), U3.3 (MOSI)
RADIO_NSS: U2.10 (PA4), U3.5 (NSS)
RADIO_SCK: U2.11 (PA5), U3.4 (SCK)
SWDCLK: J2.9, U2.20 (PA14)
SWDIO: J2.11, U2.19 (PA13)
USART2_RX: J2.7, U2.9 (PA3)
USART2_TX: J2.5, U2.8 (PA2)
VDDA: C4.1, C6.1, FB1.2, U2.5 (VDDA)
VPANEL: J1.1, J1.3, R1.2
VPANEL_SENSE: R1.1, R2.1, U2.2 (PC14)
VSUPPLY: C2.1, J1.5, R4.2, U1.3 (VI)
VSUPPLY_SENSE: R4.1, R5.1, U2.3 (PC15)

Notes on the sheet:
Antenna
Voltage Dividers
Control and programming connector:
Power Supply (from AN4467 1.2): Vdd must use a single 10uF tantalum or ceramic + 1 100nF ceramic for each Vdd.

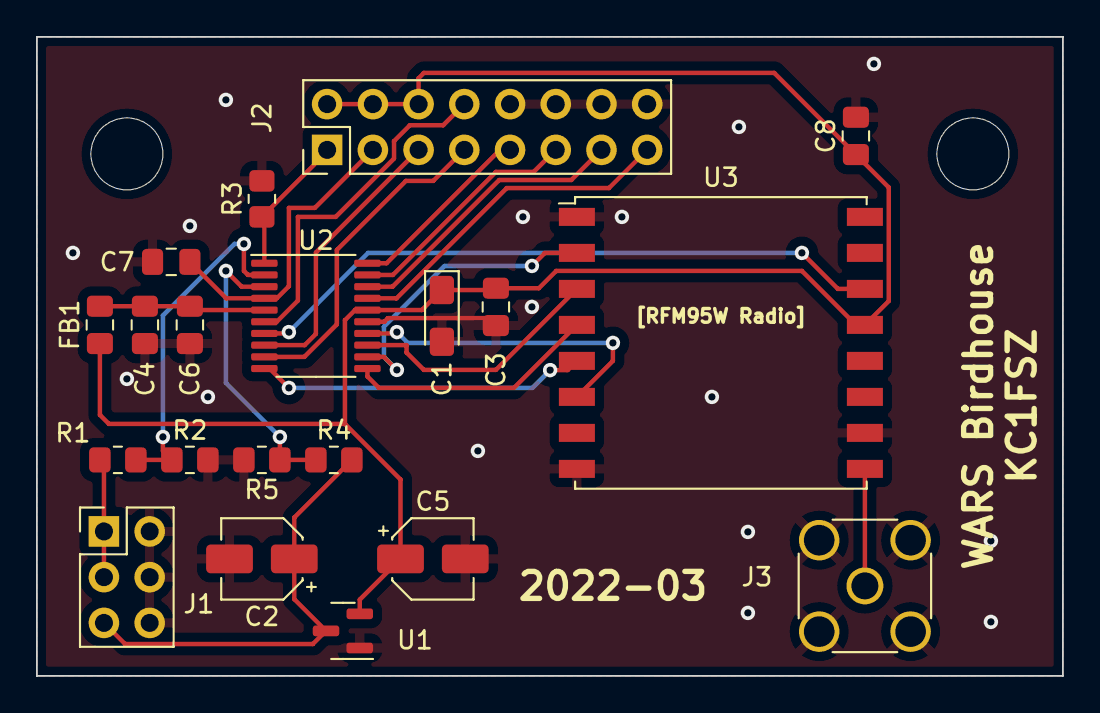
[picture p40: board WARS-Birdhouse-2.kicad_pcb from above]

Board: 2 copper layers, 57.0 x 35.5 mm, 22 parts (0 on the bottom side), 23 nets.

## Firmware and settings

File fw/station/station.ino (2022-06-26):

/* 
 * LoRa Birdhouse Mesh Network Project
 * Wellesley Amateur Radio Society
 * 
 * Copyright (C) 2022 Bruce MacKinnon
 *
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
 * You should have received a copy of the GNU General Public License
 * along with this program.  If not, see <https://www.gnu.org/licenses/>.
 */
// Current measurements:
//
// 80mA idle, 160mA transmit with normal clock
// 30mA at 10 MHz clock rate

// Prerequisites to Install 
// * philj404:SimpleSerialShell
// * contrem:arduino-timer

// Build instructions
// * Set clock frequency to 10MHz to save power (also disables WIFI and BT)

// NSS 5
// SCK 18
// MOSI 23
// MISO 19

/**
Currently using the ESP32 D1 Mini
http://www.esp32learning.com/wp-content/uploads/2017/12/esp32minikit.jpg
*/

#include <esp_task_wdt.h>
#include <SimpleSerialShell.h>
#include <arduino-timer.h>
#include <Preferences.h>
#include "BluetoothSerial.h"

#include "spi_utils.h"
#include "CircularBuffer.h"
#include "ClockImpl.h"
#include "ConfigurationImpl.h"
#include "packets.h"
#include "OutboundPacketManager.h"
#include "Instrumentation.h"
#include "RoutingTableImpl.h"
#include "MessageProcessor.h"
#include "CommandProcessor.h"

#define SW_VERSION 51

// This is the pin that is available on the D1 Mini module:
#define RST_PIN   26
// This is the ESP32 pin that is connected to the DIO0 pin on the RFM95W module.
#define DIO0_PIN  4
// NOTE: GPIO36 is the same as RTC_GPIO0 
// Generally the on-board LED on the ESP32 module
#define LED_PIN   2
// Analog input pin for measuring battery, connected via 1:2 voltage divider
#define BATTERY_LEVEL_PIN 33
// Analog input pin for measuring panel, connected via 1:6 voltage divider
#define PANEL_LEVEL_PIN 34
// NODE 5 ONLY!!!
//#define PANEL_LEVEL_PIN 35

// Watchdog timeout in seconds (NOTE: I think this time might be off because
// we are changing the CPU clock frequency)
#define WDT_TIMEOUT 5

// The time we will wait for a TxDone interrupt before giving up.  This should
// be an unusual case.
#define TX_TIMEOUT_MS (30UL * 1000UL)

// The time we will wait for a CadDone interrupt before giving up. 
#define CAD_TIMEOUT_MS (50UL)

// The time we wait for a RxDone interrupt before giving up and going 
// into idle mode.  This is done to avoid any bugs that might come
// up where we get completely stuck in the receive state.
#define RX_TIMEOUT_MS 60 * 1000

#define S_TO_US_FACTOR 1000000UL

// Deep sleep duration when low battery is detected
#define DEEP_SLEEP_SECONDS (60UL * 60UL)

// Full reboot interval
#define REBOOT_INTERVAL_SECONDS (60UL * 60UL * 24UL)

// How frequently to check the battery condition
#define BATTERY_CHECK_INTERVAL_SECONDS 30

// How frequently to check for idle potential
#define IDLE_CHECK_INTERVAL_SECONDS 15

// The definition of "idle" 
#define IDLE_INTERVAL_SECONDS 60

#define CONTROL_NODE 1
// How often the station sends its ID information to the control station
#define STATION_ID_INTERVAL_SECONDS (60UL * 60UL)

static const float STATION_FREQUENCY = 906.5;

int reset_radio();

// Used for scheduling events
auto timer = timer_create_default();

// Connect the logger stream to the SimpleSerialShell.  The shell
// global is defined (and externed) in the SimpleSerialShell module.
Stream& logger = shell;

// ===== Interface Classes ===========================================

class InstrumentationImpl : public Instrumentation {
public:

    uint16_t getSoftwareVersion() const { return SW_VERSION; }
    uint16_t getDeviceClass() const { return 2; }
    uint16_t getDeviceRevision() const { return 1; }

    uint16_t getBatteryVoltage() const { 
        // Returns the battery level in mV
        // The voltage is sampled via a 1:2 voltage divider 
        const float scale = (3.3 / 4096.0) * 2.0;
        float level = (float)analogRead(BATTERY_LEVEL_PIN) * scale;
        return level * 1000.0;
    }

    uint16_t getPanelVoltage() const { 
        // The voltage is sampled via a 1:6 voltage divider 
        const float scale = (3.3 / 4096.0) * 6.0;
        float level = (float)analogRead(PANEL_LEVEL_PIN) * scale;
        return level * 1000.0;
    }

    // Option is not implemented yet
    int16_t getTemperature() const { return 0; }
    int16_t getHumidity() const { return  0; }

    void restart() { 
        // This is scheduled in the background to make sure that any final communication
        // has time to happen.
        timer.in(2 * 1000, _backgroundRestart);
        logger.println("INF: Restart scheduled");
    }

    void restartRadio() {
        reset_radio();
    }

    void sleep(uint32_t ms) {
        sleep(ms);
    }

private:

    static bool _backgroundRestart(void*) {
        ESP.restart();
        return false;
    }    
};

// Used for persistent storage
static Preferences nvram;

static ClockImpl mainClock;
Clock& systemClock = mainClock;

static ConfigurationImpl mainConfig(nvram);
Configuration& systemConfig = mainConfig;

static InstrumentationImpl instrumentation;
Instrumentation& systemInstrumentation = instrumentation;

static RoutingTableImpl routingTable(nvram);
RoutingTable& systemRoutingTable = routingTable;

// We keep a pretty small TX buffer because the main area where we keep 
// outbound packets is in the MessageProcessor.
static CircularBufferImpl<256> txBuffer(0);
// There is a two-byte OOB allocation here for the RSSI data on receive
static CircularBufferImpl<2048> rxBuffer(2);

static MessageProcessor messageProcessor(mainClock, 
  rxBuffer, txBuffer, routingTable, instrumentation, mainConfig, 20 * 1000, 2 * 1000);
MessageProcessor& systemMessageProcessor = messageProcessor;

// The states of the state machine
enum State { IDLE_STATE, RX_STATE, TX_STATE, CAD_STATE };

// The overall state
static volatile State state = State::IDLE_STATE;
// This is volatile because it is set inside of the ISR context
static volatile bool isrHit = false;

// The time when the last receive was started.  Used to manage
// timeouts.
static volatile uint32_t startRxTime = 0;
// The time when we started the last transmission.  This is needed 
// to create a timeout on transmissions so we don't accidentally get 
// stuck in a transmission.
static volatile uint32_t startTxTime = 0;
// The time when we started the last channel activity detection.
// This is needed to manage timeouts.
static volatile uint32_t startCadTime = 0;
// The time when the last channel activity was seen.. Used to avoid
// transmission when there is receive activity going on.
static volatile uint32_t lastActivityTime = 0;

// Alternate Serial Port
BluetoothSerial SerialBT;

/**
 * @brief This is the actual ISR that is called by the Arduino run-time.
 */
void IRAM_ATTR isr() {
    // NOTE: We've had so many problems with interrupt enable/disable on the ESP32
    // so now we're just going to set a flag and let everything happen in the loop()
    // context. This eliminates a lot of risk around concurrency, etc.
    isrHit = true;
}

static void start_Tx() {

    //logger.println("start_Tx");

    // At this point we have something pending to be sent.
    // Go into stand-by so we are allowed to fill the FIFO
    // (see page 34)
    set_mode_STDBY();

    // Pop the data off the TX queue into the transmit buffer.  
    unsigned int tx_buf_len = 256;
    uint8_t tx_buf[tx_buf_len];
    txBuffer.pop(0, tx_buf, &tx_buf_len);

    // Move the data into the radio FIFO
    write_message(tx_buf, tx_buf_len);
    
    // Go into transmit mode
    state = State::TX_STATE;
    startTxTime = mainClock.time();
    enable_interrupt_TxDone();
    set_mode_TX();
}

/**
 * @brief Put the radio into receive mode and enable the RxDone interrupt.
 */
static void start_Rx() {
    state = State::RX_STATE;
    startRxTime = mainClock.time();
    // Ask for interrupt when receiving
    enable_interrupt_RxDone();
    set_mode_RXCONTINUOUS();
}

/**
 * @brief Put the radio into CAD (channel activity detect) mode
 * and enable the CadDone interrupt.
 * 
 * NOTE: It appears that we don't get the CadDone interrupt under
 * normal (inactive) circumstances.  So a timeout is used to stop
 * the CAD process later.
 */
static void start_Cad() {      

    //logger.println("start_Cad");

    state = State::CAD_STATE;
    startCadTime = mainClock.time();
    enable_interrupt_CadDone();
    set_mode_CAD();  
}

static void start_Idle() {
    state = State::IDLE_STATE;
    set_mode_STDBY();
}

/**
 * @brief This is called when the radio reports the end of a 
 * transmission sequence.
 * 
 * This gets called from the main processing loop.
 */
static void event_TxDone(uint8_t irqFlags) {   

    //logger.println("TxDone");

    // If we expected this event
    if (state == State::TX_STATE) {
        // After transmit the radio goes back to standby mode
        // automatically
        state = State::IDLE_STATE;
    }
    // Unexpected event
    else {
        logger.println("WRN: Unexpected TxDone");
        start_Idle();
    }
} 

/**
 * @brief This is called when a complete message is received.
 * 
 * This gets called from the main processing loop.
 */
static void event_RxDone(uint8_t irqFlags) {

    //logger.println("RxDone");

    // Record that some activity was seen on the channel
    lastActivityTime = mainClock.time();

    // Expected
    if (state == State::RX_STATE) {
        // Make sure we don't have any errors
        if (irqFlags & 0x20) {
            if (systemConfig.getLogLevel() > 0) {
               logger.println("WRN: CRC error");
            }
            // Message is ignored
        }
        else {
            // How much data is available? RxBytesNb
            const uint8_t len = spi_read(0x13);

            // We do nothing for zero-length messages
            if (len == 0) {
                return;
            }

            // Set the FIFO read pointer to the beginning of the 
            // packet we just got. FifoAddrPtr=FifoRxCurrentAddr.  
            spi_write(0x0d, spi_read(0x10));

            // Stream received data in from the FIFO. 
            uint8_t rx_buf[256];
            spi_read_multi(0x00, rx_buf, len);
            
            // Grab the RSSI value from the radio
            int8_t lastSnr = (int8_t)spi_read(0x19) / 4;
            int16_t lastRssi = spi_read(0x1a);
            if (lastSnr < 0)
                lastRssi = lastRssi + lastSnr;
            else
                lastRssi = (int)lastRssi * 16 / 15;
            // We are using the high frequency port
            lastRssi -= 157;

            // Put the RSSI (OOB) and the entire packet into the circular queue for 
            // later processing.
            rxBuffer.push((const uint8_t*)&lastRssi, rx_buf, len);
        }
        // NOTE: Stay in RX state
    }
    // Unexpected 
    else {
        logger.println("WRN: Unexpected RxDone");
        start_Idle();
    }
}

/**
 * @brief This function is called when the radio completes a CAD cycle
 * and it is determined that these is channel activity. 
 */
static void event_CadDone(uint8_t irqFlags) {

    // Expected
    if (state == State::CAD_STATE) {
        // This is the case where activity was detected
        if (irqFlags & 0x01) {
            logger.println("INF: CadDone Detection");
            lastActivityTime = mainClock.time();
            // Radio goes back to standby automatically after CAD
            state = State::IDLE_STATE;
        }
    }
    // Unexpected
    else {
        logger.println("WRN: Unexpected CadDone");
        start_Idle();
    }
}

/**
 * @brief This function gets called from inside of the main processing loop.  It looks
 * to see if any interrupt activity has been detected and, if so, figure 
 * out what kind of interrupt was reported and calls the correct handler.
 */ 
static void check_for_interrupts() {

    // Look at the flag that gets set by the ISR itself
    if (!isrHit) {
        return;
    } else {
        if (systemConfig.getLogLevel() > 0) {
            logger.println("INF: Int");
        }
    }

    // *******************************************************************************
    // Critical Section:
    // Here we make sure that the clearing of the isr_hit flag and the unloading 
    // of the pending interrupts in the radio's IRQ register happen atomically.
    // We are avoding the case where 
    noInterrupts();

    isrHit = false;

    // Read and reset the IRQ register at the same time:
    uint8_t irq_flags = spi_write(0x12, 0xff);    
    
    // We saw a comment in another implementation that said that there are problems
    // clearing the ISR sometimes.  Notice we do a logical OR so we don't loose anything.
    irq_flags |= spi_write(0x12, 0xff);    

    interrupts();
    // *******************************************************************************
    
    // RxDone 
    if (irq_flags & 0x40) {
        event_RxDone(irq_flags);
    }
    // TxDone
    if (irq_flags & 0x08) {
        event_TxDone(irq_flags);
    }
    // CadDone
    if (irq_flags & 0x04) {
        event_CadDone(irq_flags);
    }
}

static void event_tick_Idle() {

    // Make sure the radio is in the state that we expect
    uint8_t state = spi_read(0x01);  
    if (state != 0x81) {
        logger.println("WRN: Radio in unexpected state.");
        reset_radio();
        return;
    }
      
    // Check to see if there is data waiting to go out
    if (!txBuffer.isEmpty()) {
        // Launch a CAD check to see if the channel is clear
        start_Cad(); 
    } 
    else {
        start_Rx();
    }
}

static void event_tick_Tx() {
    // Check for the case where a transmission times out
    if (mainClock.time() - startTxTime > TX_TIMEOUT_MS) {
        logger.println("ERR: TX time out");
        start_Idle();
    }
}

static void event_tick_Rx() {

    // Check for pending transmissions.  If nothing is pending then 
    // return without any state change.
    if (!txBuffer.isEmpty()) {
        // At this point we know there is something pending.  We first 
        // go into CAD mode to make sure the channel is innactive.
        // A successful CAD check (with no detection) will trigger 
        // the transmission.
        start_Cad();
    }

    // Check for the case where a receive times out
    if (mainClock.time() - startRxTime > RX_TIMEOUT_MS) {
        start_Idle();
    }
}

static void event_tick_Cad() {
    // Check for the case where a CAD check times out.  A random timeout is 
    // used to try to reduce collisions
    if ((mainClock.time() - startCadTime) > (CAD_TIMEOUT_MS * random(1, 3))) {
        // If a CAD times out then that means that it is safe 
        // to transmit. 
        if (!txBuffer.isEmpty()) {
            start_Tx();
        } else {
            start_Idle();
        }
    }
}

// Call periodically to look for timeouts or other pending activity.  
// This will happen on the regular application thread.
static bool event_tick(void*) {
    if (state == State::RX_STATE) {
        event_tick_Rx();
    } else if (state == State::TX_STATE) {
        event_tick_Tx();
    } else if (state == State::CAD_STATE) {
        event_tick_Cad();
    } else if (state == State::IDLE_STATE) {
        event_tick_Idle();
    } 
    return true;
}

// --------------------------------------------------------------------------
// Radio Utilty Functions
// 
// This reference will be very important to you:
// https://www.hoperf.com/data/upload/portal/20190730/RFM95W-V2.0.pdf
// 
// The LoRa register map starts on page 103.

static void set_mode_SLEEP() {
    spi_write(0x01, 0x00);  
}

static void set_mode_STDBY() {
    spi_write(0x01, 0x01);  
}

static void set_mode_TX() {
    spi_write(0x01, 0x03);
}

static void set_mode_RXCONTINUOUS() {
    spi_write(0x01, 0x05);
}

static void set_mode_RXSINGLE() {
    spi_write(0x01, 0x06);
}

static void set_mode_CAD() {
    spi_write(0x01, 0x07);
}

// See table 17 - DIO0 is controlled by bits 7-6
static void enable_interrupt_TxDone() {
    spi_write(0x40, 0x40);
}

// See table 17 - DIO0 is controlled by bits 7-6
static void enable_interrupt_RxDone() {
    spi_write(0x40, 0x00);
}

// See table 17 - DIO0 is controlled by bits 7-6
static void enable_interrupt_CadDone() {
    spi_write(0x40, 0x80);
}

/** Sets the radio frequency from a decimal value that is quoted
 *   in MHz.
 */
// See page 103
void set_frequency(float freq_mhz) {
    const float CRYSTAL_MHZ = 32000000.0;
    const float FREQ_STEP = (CRYSTAL_MHZ / 524288);
    const uint32_t f = (freq_mhz * 1000000.0) / FREQ_STEP;
    spi_write(0x06, (f >> 16) & 0xff);
    spi_write(0x07, (f >> 8) & 0xff);
    spi_write(0x08, f & 0xff);
}

void write_message(uint8_t* data, uint8_t len) {
    // Move pointer to the start of the FIFO
    spi_write(0x0d, 0);
    // The message
    spi_write_multi(0x00, data, len);
    // Update the length register
    spi_write(0x22, len);
}

int reset_radio() {
  
    pinMode(RST_PIN, OUTPUT);
    digitalWrite(RST_PIN, HIGH);
    delay(5);
    digitalWrite(RST_PIN, LOW);
    delay(5);
    digitalWrite(RST_PIN, HIGH);
    // Float the reset pin
    pinMode(RST_PIN, INPUT);
    // Per datasheet, wait 5ms after reset
    delay(5);
    // Not sure if this is really needed:
    delay(250);

    // Initialize the radio
    if (init_radio() != 0) {
        logger.println(F("ERR: Problem with radio initialization"));
        return -1;
    }

    logger.println(F("INF: Radio initialized"));

    // Flash the LED as a diagnostic indicator 
    digitalWrite(LED_PIN, HIGH);
    delay(200);
    digitalWrite(LED_PIN, LOW);
    delay(200);
    digitalWrite(LED_PIN, HIGH);
    delay(200);
    digitalWrite(LED_PIN, LOW);

    start_Idle();

    return 0;  
}

/**
 * @brief Sets the Over Current Protection register.
 * 
 * @param current_ma 
 */
static void set_ocp(uint8_t current_ma) {

    uint8_t trim = 27;
    if (current_ma <= 120) {
        trim = (current_ma - 45) / 5;
    } else if (current_ma <= 240) {
        trim = (current_ma + 30) / 10;
    }
    spi_write(0x0b, 0x20 | (0x1F & trim));
}

static void setLowDatarate() {

    // called after changing bandwidth and/or spreading factor
    //  Semtech modem design guide AN1200.13 says 
    // "To avoid issues surrounding  drift  of  the  crystal  reference  oscillator  due  to  either  temperature  change  
    // or  motion,the  low  data  rate optimization  bit  is  used. Specifically for 125  kHz  bandwidth  and  SF  =  11  and  12,  
    // this  adds  a  small  overhead  to increase robustness to reference frequency variations over the timescale of the LoRa packet."
 
    // read current value for BW and SF
    uint8_t bw = spi_read(0x1d) >> 4;	// bw is in bits 7..4
    uint8_t sf = spi_read(0x1e) >> 4;	// sf is in bits 7..4
   
    // calculate symbol time (see Semtech AN1200.22 section 4)
    float bw_tab[] = { 7800, 10400, 15600, 20800, 31250, 41700, 62500, 
      125000, 250000, 500000};
    float bandwidth = bw_tab[bw];
    float symbolTime = 1000.0 * pow(2, sf) / bandwidth;	// ms
   
    // the symbolTime for SF 11 BW 125 is 16.384ms. 
    // and, according to this :- 
    // https://www.thethingsnetwork.org/forum/t/a-point-to-note-lora-low-data-rate-optimisation-flag/12007
    // the LDR bit should be set if the Symbol Time is > 16ms
    // So the threshold used here is 16.0ms
 
    // the LDR is bit 3 of register 0x26
    uint8_t current = spi_read(0x26) & ~0x08; // mask off the LDR bit
    if (symbolTime > 16.0)
      spi_write(0x26, current | 0x08);
    else
      spi_write(0x26, current);   
}

/** 
 *  All of the one-time initialization of the radio
 */
int init_radio() {

    // Check the radio version to make sure things are connected
    uint8_t ver = spi_read(0x42);
    if (ver != 18) {
        return -1;
    }

    // Switch into Sleep mode, LoRa mode
    spi_write(0x01, 0x80);
    // Wait for sleep mode 
    delay(10); 

    // Make sure we are actually in sleep mode
    if (spi_read(0x01) != 0x80) {
        return -1; 
    }

    // Setup the FIFO pointers
    // TX base:
    spi_write(0x0e, 0);
    // RX base:
    spi_write(0x0f, 0);

    set_frequency(STATION_FREQUENCY);

    // Set LNA boost
    spi_write(0x0c, spi_read(0x0c) | 0x03);

    // AgcAutoOn=LNA gain set by AGC
    spi_write(0x26, 0x04);

    // DAC enable (adds 3dB)
    spi_write(0x4d, 0x87);

    // Turn on PA and set power to +20dB
    // PaSelect=1
    // OutputPower=17 (20 - 3dB from DAC)
    spi_write(0x09, 0x80 | ((20 - 3) - 2));

    // Set OCP to 140 (as per the Sandeep Mistry library)
    set_ocp(140);

    // Go into stand-by
    set_mode_STDBY();

    // Configure the radio
    uint8_t reg = 0;

    // 7-4: 0111  (125k BW)
    // 3-1: 001   (4/5 coding rate)
    // 0:   0     (Explicit header mode)
    reg = 0b01110010;
    spi_write(0x1d, reg);

    // 7-4:   9 (512 chips/symbol, spreading factor 9)
    // 3:     0 (TX continuous mode normal)
    // 2:     1 (CRC mode on)
    // 1-0:   0 (RX timeout MSB) 
    reg = 0b10010100;
    spi_write(0x1e, reg);

    // Preable Length=8 (default)
    // Preamble MSB and LSB
    //spi_write(0x20, 8 >> 8);
    //spi_write(0x21, 8 & 0xff);

    setLowDatarate();

    return 0;
}

static bool isDelim(char d, const char* delims) {
    const char* ptr = delims;
    while (*ptr != 0) {
        if (d == *ptr) {
            return true;
        }
        ptr++;
    }
    return false;
}
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
void loop() {

  // Check to see if any interrupts were fired
  check_for_interrupts();
 
  // Check for shell activity
  shell.executeIfInput();
  
  // Service the timers
  timer.tick();

  // Perform any message processing that is pending
  systemMessageProcessor.pump();

  // Keep the watchdog alive
  esp_task_wdt_reset();

  // Serial2 checks
  if (!alternateSerial && SerialBT.available()) {
    char c = SerialBT.read();
    // Look for the activation character
    if (c == '$') {
      // Switch
      Serial.println("INF: Switching to Serial2");
      shell.attach(SerialBT);
      alternateSerial = true;
    }
  }
}

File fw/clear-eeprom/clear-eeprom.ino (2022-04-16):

#include <EEPROM.h>
#include <Preferences.h>

void setup() {
  Serial.begin(115200);
  delay(100);
  Serial.println("Clearing EEPROM ...");
  for (unsigned int i = 0; i < 256; i++)
    EEPROM.write(i,0);
  EEPROM.commit();
  Serial.println("Clearing NVRAM ...");
  Preferences preferences;  
  preferences.clear();
  Serial.println("Done!");
}

void loop() {
}

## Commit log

2021-12-27 Added batterly level and low power checking
2021-12-27 Factored out SPI code
2021-12-28 Version 15 - Adjusted power
2022-01-06 Changed to a formal timer class
2022-02-26 Added panel voltage
2022-03-04 Corrected a bug with deep sleep timer, added REM per Charlie's suggestion
2022-03-31 Added KiCAD files
    [WARS-Birdhouse-2.kicad_pcb, WARS-Birdhouse-2.kicad_sch]
2022-04-03 Added filter for messages targeted at a different node.
2022-04-03 Added Configiration interface
    [Configuration.h]
2022-04-07 Configuration testing?
    [ConfigurationImpl.h]
2022-04-07 Working on test cases
    [Configuration.h]
2022-04-09 Refactoring for V2
    [Configuration.h, ConfigurationImpl.h]
2022-04-10 Working on boot count/sleep count
    [Configuration.h, ConfigurationImpl.h]
2022-04-14 Resolved some NVRAM problems
    [ConfigurationImpl.h]
2022-04-15 Added passcode, clean up
    [Configuration.h, ConfigurationImpl.h]
2022-04-15 Fixed bug with passcode
    [Configuration.h, ConfigurationImpl.h]
2022-04-16 Renamed the sketch to station
    [Configuration.h, ConfigurationImpl.h]
2022-04-17 Added retry ignore, added CAD, added RSSI on EDR packet
2022-04-17 Formatting cleanup, reset bug
    [station.ino]
2022-04-18 Added command mode, text format
    [Configuration.h, ConfigurationImpl.h]
2022-04-18 added station id timer
2022-06-11 Added reset when radio is in wrong state
    [station.ino]
2022-10-22 Added docs
    [Packet Format.ods]

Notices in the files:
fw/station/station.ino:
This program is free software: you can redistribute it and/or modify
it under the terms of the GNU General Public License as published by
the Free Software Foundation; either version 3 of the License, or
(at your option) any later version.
